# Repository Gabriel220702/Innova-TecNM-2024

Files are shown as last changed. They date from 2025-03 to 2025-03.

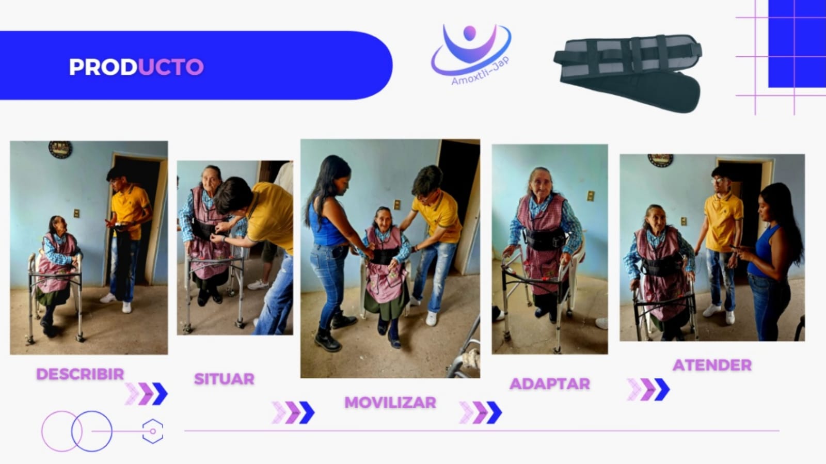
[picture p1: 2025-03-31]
Innova TecNM 2024 Etapa Regional/Página Web/img/portfolio/Producto.jpg

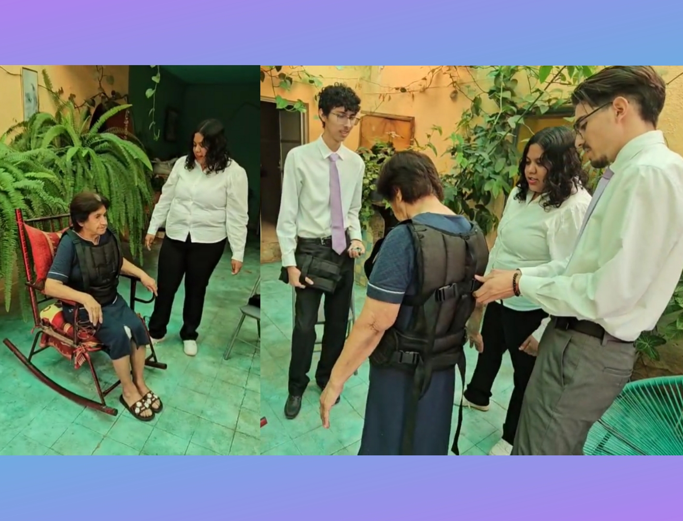
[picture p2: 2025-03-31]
Innova TecNM 2024 Etapa Regional/Página Web/img/portfolio/Abuelita con Chaleco 2.jpg

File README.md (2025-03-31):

# 💜**Amoxtli-Jap**💜  

## 📌 **Autor:** Gabriel Carrizales  
📍 **Institución:** Instituto Tecnológico Superior de la Región de los Llanos (ITSRLL)  
🎓 **Carrera:** Ingeniería Mecatrónica  

---

## 📖 **Descripción del Proyecto**  
Amoxtli-Jap es un dispositivo vestible en forma de cinturón o chaleco diseñado para mejorar la seguridad y bienestar de adultos mayores. Su innovador diseño integra sensores y tecnología para la detección de caídas y ubicación en tiempo real, ofreciendo una solución eficiente para el monitoreo y asistencia de personas vulnerables.  

---

## 📂 **Características Principales**  

🔹 **Diseño Ergonómico** 🎽  
- Fabricado con materiales textiles cómodos y resistentes.  

🔹 **Tecnología Integrada** 🔌  
- ESP32, GPS Neo-6M, giroscopio/acelerómetro MPU6050, buzzer, push button y baterías recargables.  

🔹 **Detección de Caídas** ⚠️  
- Sistema de monitoreo en tiempo real para alertar a familiares o cuidadores.  

🔹 **Ubicación en Tiempo Real** 🌍  
- Integración con Google Maps para rastrear la posición del usuario.  

🔹 **Alertas de Emergencia** 📢  
- Notificaciones inmediatas mediante sonido y mensajes vía WhatsApp.  

---

## 🏆 **Participación en Eventos**  
Amoxtli-Jap ha sido presentado en diversas competencias y ferias tecnológicas, destacando en las siguientes etapas:  

1. 🏫 **Innovatec Etapa Local** - Instituto Tecnológico Superior de la Región de los Llanos, Guadalupe Victoria, Durango.  
2. 🏙️ **Innovatec Etapa Regional** - Instituto Tecnológico de Nuevo León, Monterrey, Nuevo León.  
3. 🏅 **COCYTED** - Centro de Ciencia y Tecnología del Estado de Durango, Victoria de Durango, Durango.  

---

## 👥 **Integrantes del Equipo**  
El proyecto ha sido desarrollado por un equipo comprometido de estudiantes de Ingeniería Mecatrónica e Ingeniería en Administración de Empresas, enfocados en la innovación y aplicación de tecnología para el beneficio social.  

---

## 💻 **Tecnologías Utilizadas**  
✅ **ESP32** – Microcontrolador principal  
✅ **Neo-6M** – GPS para ubicación  
✅ **MPU6050** – Sensor de aceleración y giroscopio  
✅ **Python y C++** – Programación de algoritmos  
✅ **Google Maps API** – Integración de geolocalización  

---

## 📩 **Contacto**  
Para más información sobre el proyecto Amoxtli-Jap, puedes ponerte en contacto a través de [amoxtlijap2024@gmail.com] o visitar nuestra página oficial o redes sociales.  

📌 **Página Oficial:** [Amoxtli-Jap](https://home.amoxtli-jap.com/index.php)  
📌 **Facebook:** [Amoxtli-Jap en Facebook](https://www.facebook.com/profile.php?id=61563272744083)  
📌 **YouTube:** [Amoxtli-Jap en YouTube](https://www.youtube.com/@Amoxtli-Jap)  

---

<p align="center">

  
  
  

</p> 

🚀 **¡Innovando por el bienestar de nuestros adultos mayores!** 💙💜

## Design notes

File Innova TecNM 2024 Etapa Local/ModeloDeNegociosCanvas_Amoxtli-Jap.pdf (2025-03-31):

SOCIOS CLAVE | ACTIVIDADES CLAVE
PROPUESTA DE VALOR

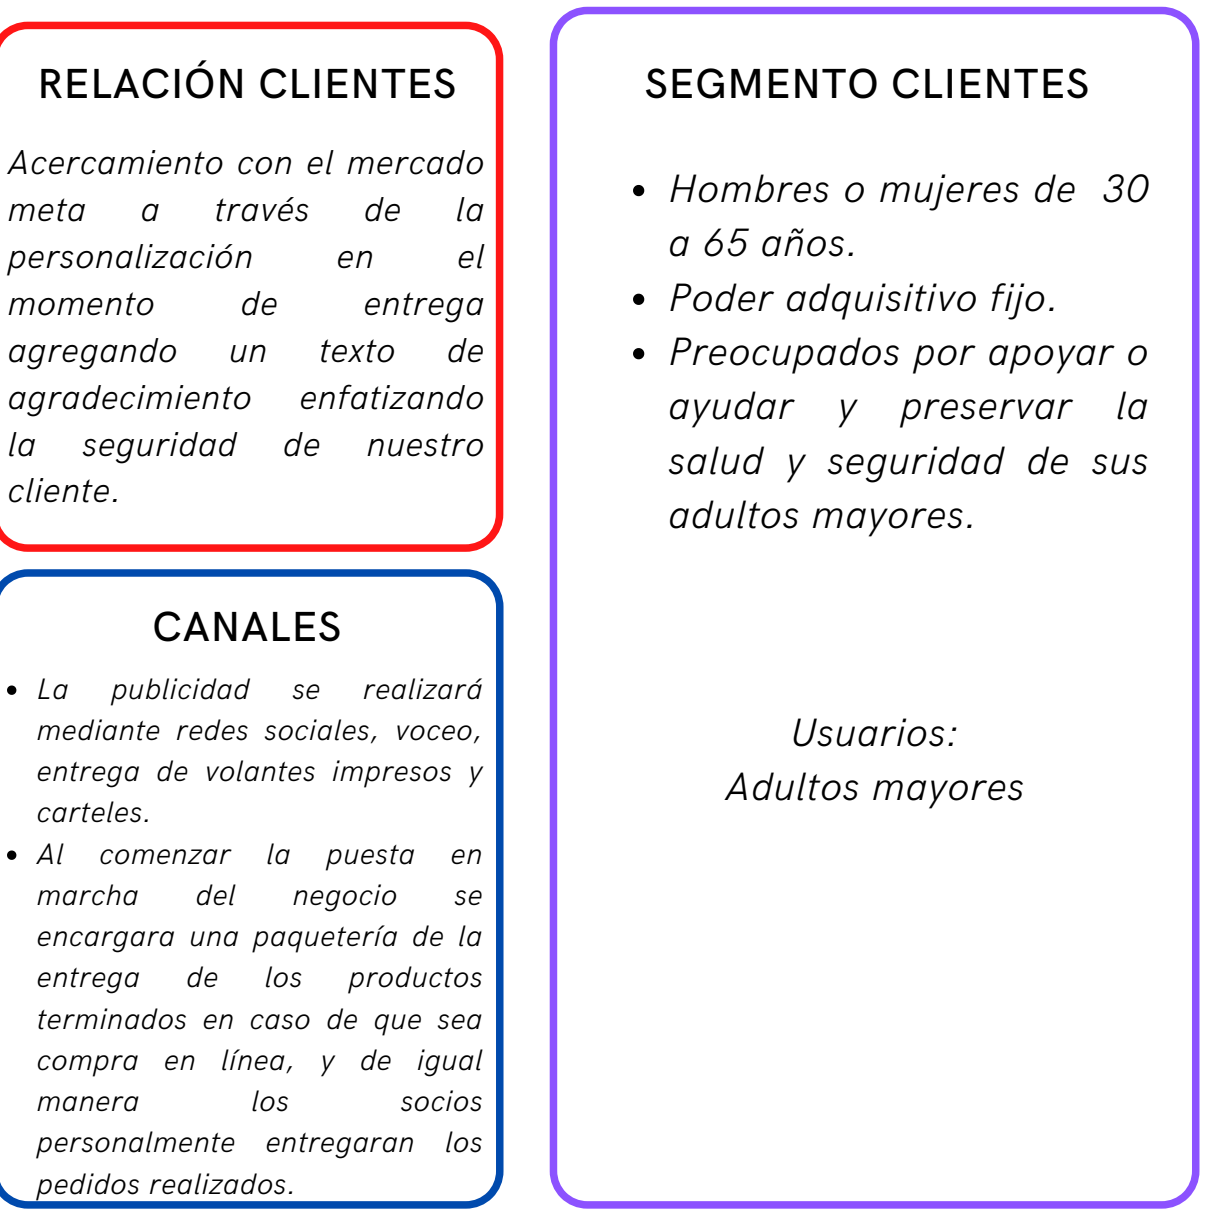
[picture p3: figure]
CANALES; RELACIÓN CLIENTES; SEGMENTO CLIENTES; Hombres o mujeres de 30 a 65 años. Poder adquisitivo fijo. Preocupados por apoyar o ayudar y preservar la salud y seguridad de sus adultos mayores.; Usuarios: Adultos mayores; publicidad; realizará; mediante redes sociales, voceo, entrega de volantes impresos y carteles. Al comenzar la puesta en; marcha; del; negocio; encargara una paquetería de la; entrega; los; productos; terminados en caso de que sea compra en línea, y de igual; manera; socios; personalmente entregaran los pedidos realizados.; Acercamiento con el mercado; meta; través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
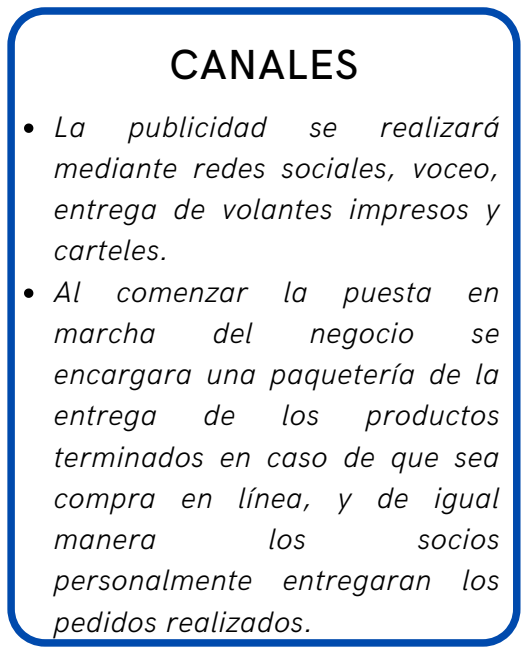
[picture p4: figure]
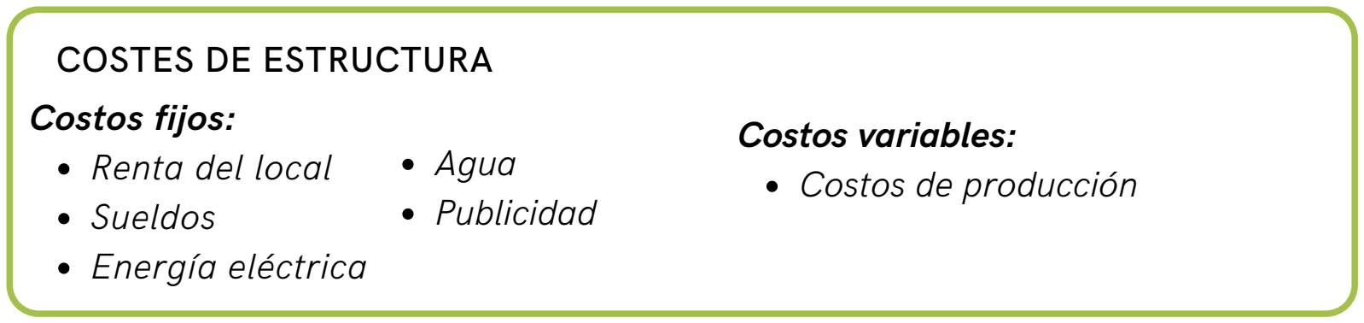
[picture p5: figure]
COSTES DE ESTRUCTURA Costos fijos: Renta del local Sueldos Energía eléctrica; Costos variables: Costos de producción; Agua Publicidad

FUENTES DE INGRESO

# M O DE L O DE N E G O CI O S CA N VAS A M O XT L I - JAP

Dispositivo auxiliar de monitoreo para facil movilidad y traslado de
adultos | mayores, | implentando
tecnología sensorial y ergonomía para el cuidado de adultos mayores. Mediante el monitoreo
constante | de | movimientos | y
respuesta rápida ante caídas. Ayudando a generar un resgitro de estadísticas vitales para medidas preventivas. Diseño ergonómico y
funcional | que | prioriza | la
comodidad | y | seguridad | del
usuario. | Genera | confianza | y
dignidad | en | situaciones | de
emergencia. Líder en innovación y
cuidado | personalizado | para
poblaciones vulnerables.

Adquisición de materia prima
(Sensores, | tarjeta | de
conectividad, telas, etc.)
Ensamble y programación de circuito y cinturón
Prueba de tarjeta de conectividad y de sensores
Actividades de mercadotecnia Distribuir el producto
Innovacion | y | desarrollo
tecnológico

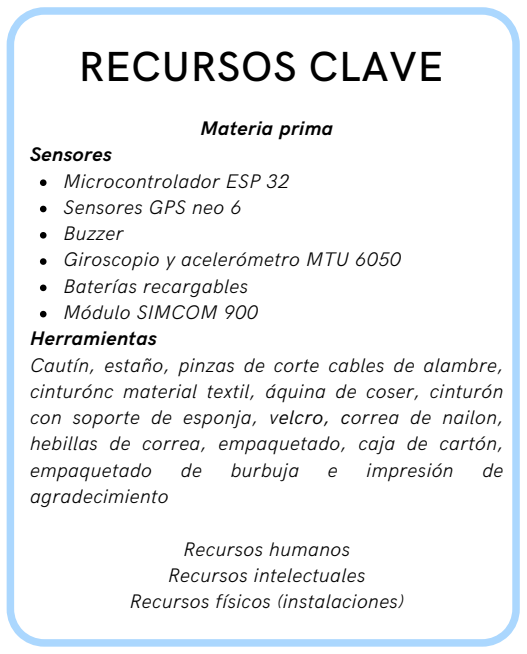
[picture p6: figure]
RECURSOS CLAVE; Materia prima; Sensores Microcontrolador ESP 32 Sensores GPS neo 6 Buzzer Giroscopio y acelerómetro MTU 6050 Baterías recargables Módulo SIMCOM 900 Herramientas; empaquetado; burbuja; impresión; agradecimiento; Recursos humanos Recursos intelectuales Recursos físicos (instalaciones)

Cautín, estaño, pinzas de corte cables de alambre, cinturónc material textil, áquina de coser, cinturón con soporte de esponja, velcro, correa de nailon, hebillas de correa, empaquetado, caja de cartón,

Comercios en línea o de la región que se dediquen a la electrónica.
Comercios que se dediquen a la venta de textiles.
Socios de plataformas en
venta | de | productos
ortopédicos.
Farmacias físicas

La principal fuente de ingresos será la venta de los cinturones con sensores en $1,200.00 MXN
Los pagos se recibirán en efectivo, de contado y en transferencias.

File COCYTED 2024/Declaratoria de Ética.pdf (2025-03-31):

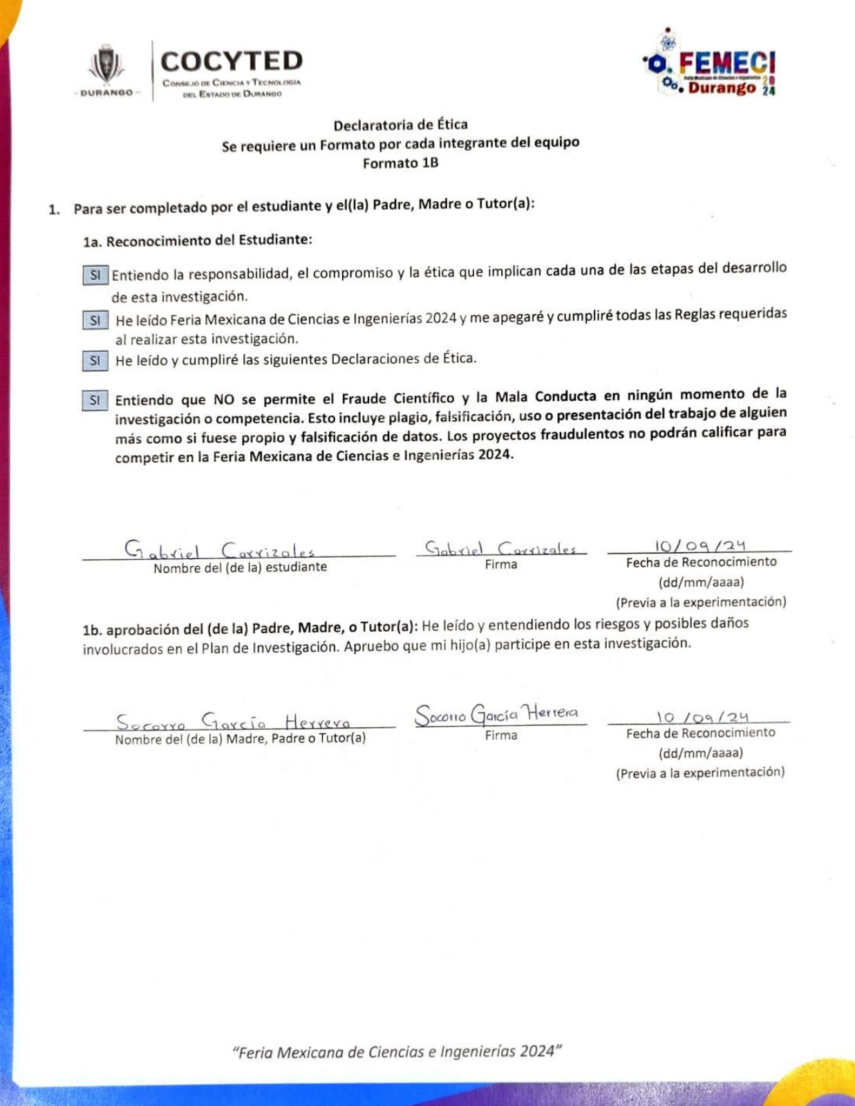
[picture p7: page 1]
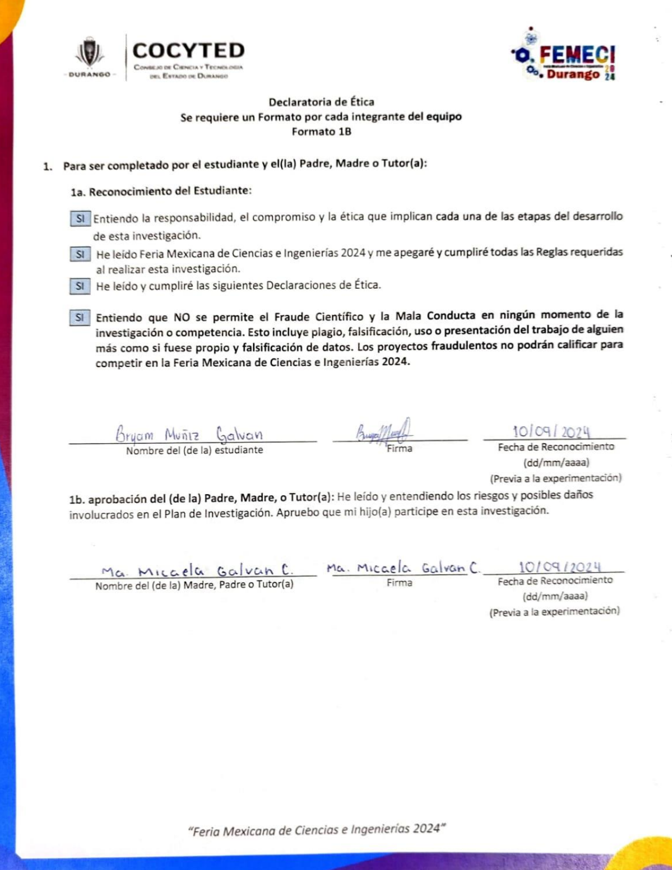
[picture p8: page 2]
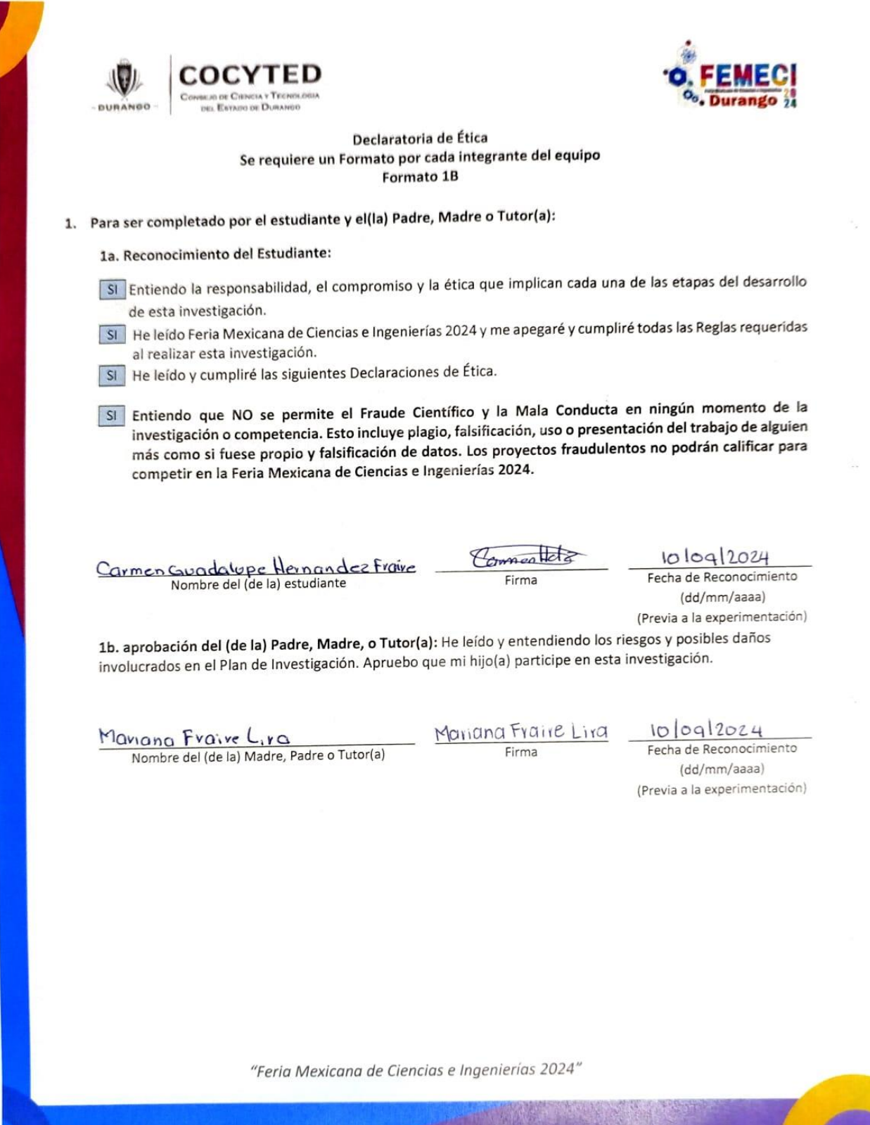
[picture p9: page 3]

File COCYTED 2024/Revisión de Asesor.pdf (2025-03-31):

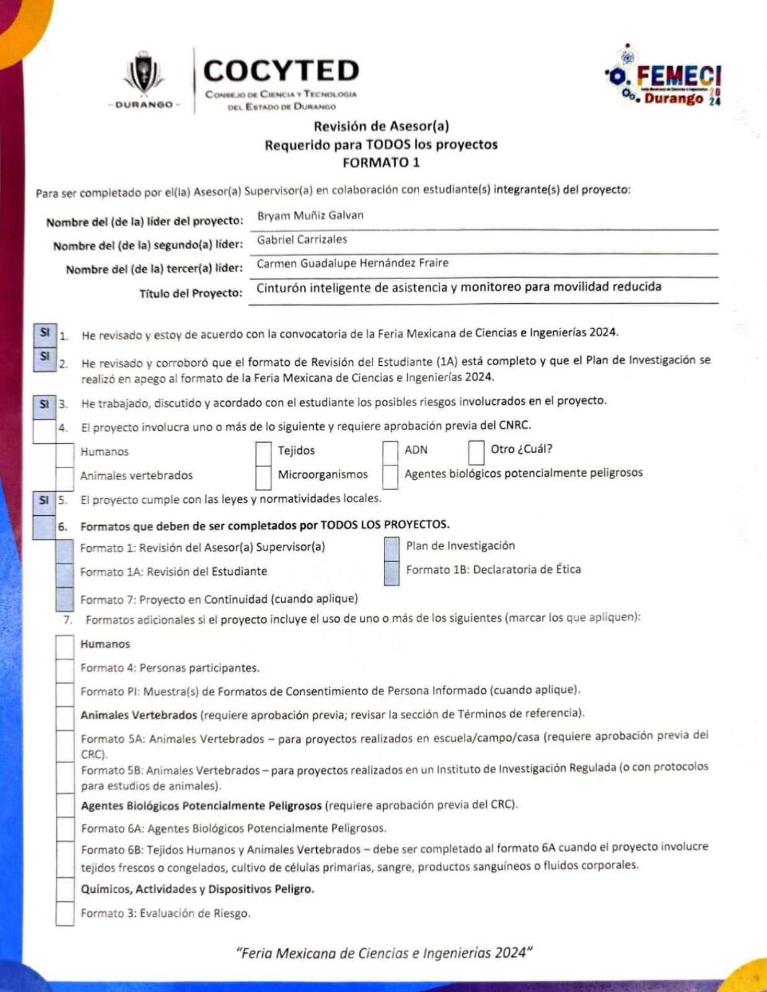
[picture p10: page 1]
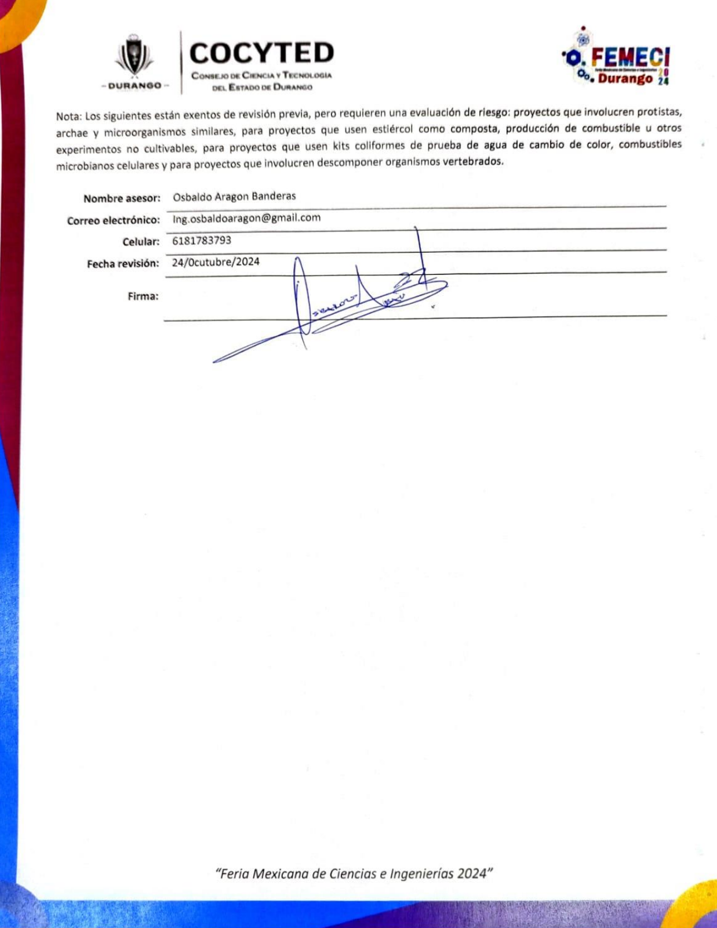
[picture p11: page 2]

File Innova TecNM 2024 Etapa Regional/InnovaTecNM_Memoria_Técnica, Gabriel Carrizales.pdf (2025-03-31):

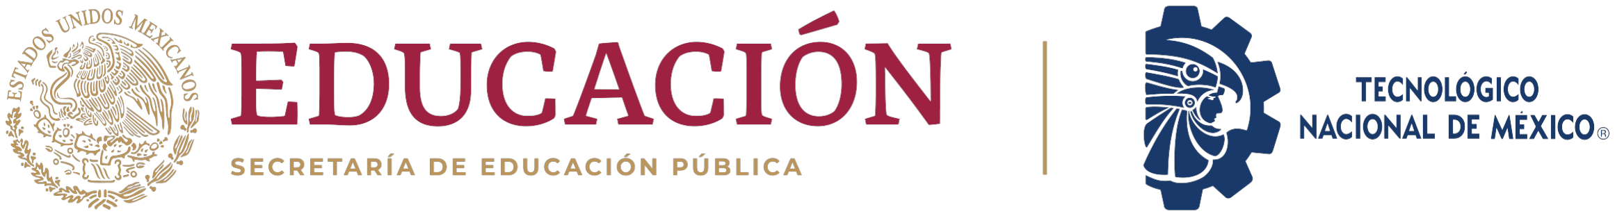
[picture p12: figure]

Cumbre Nacional de Desarrollo Tecnológico, Emprendimiento e Innovación, InnovaTecNM 2024 Instituto Tecnológico Superior de La Región de los Llanos
Región 2
Etapa Regional
MEMORIA DEL PROYECTO
Folio: | 54384-15 | Nombre corto: | Amoxtli-Jap
Nombre descriptivo: | Cinturón auxiliar para monitoreo de alerta para la detección de caídas en adultos mayores.
Categoría: | Servicios para la Salud
Área de aplicación: | Salud y bienestar de los adultos mayores
Naturaleza técnica: | Ciencias Eléctricas

Autores
BRYAM MUÑIZ GALVAN | Ing. en Mecatrónica | 6
GABRIEL CARRIZALES | Ing. en Mecatrónica | 6
ABRIL ADRIANA SANCHEZ VALENZUELA | Ing. en Administración | 6
CARMEN GUADALUPE HERNANDEZ FRAIRE | Ing. en Mecatrónica | 6
MIGUEL ÁNGEL RODRIGUEZ HERNANDEZ | Ing. en Mecatrónica | 6

Asesores
OSBALDO ARAGÓN BANDERAS | ing.osbaldoaragon@gmail.com
JESUS LEONEL ARCE VALDEZ | jlaitsrll@hotmail.com

ER. SS. Descripción de la propuesta

El objetivo del dispositivo se centra en proporcionar traslados seguros para los usuarios y optimizar la capacidad de respuesta ante eventos críticos, minimizando el riesgo de lesiones graves derivadas de caídas. Además, brinda una mayor sensación de seguridad a los usuarios y sus familias, gracias a la implementación de sujetadores de alta resistencia que facilitan traslados por parte de cuidadores para quienes lo necesitan.

Amoxtli-Jap es un avanzado dispositivo de monitoreo médico vestible, diseñado para el seguimiento de adultos mayores y personas con movilidad reducida. El dispositivo está integrado con sensores de alta precisión que permiten un monitoreo continuo y detallado del posicionamiento y movilidad del usuario. Su operatividad se fundamenta en la implementación de tecnología de vanguardia, incluyendo sensores de caídas y algoritmos de procesamiento de datos, que permiten analizar los patrones de movimiento en tiempo real.

Al detectar una anomalía en el movimiento, como una caída, Amoxtli-Jap activa automáticamente un protocolo de alerta. El cual comunica el incidente de forma inalámbrica a familiares, cuidadores o sistemas de respuesta médica de emergencia, garantizando una intervención rápida.

Amoxtli-Jap sobresale en el ámbito biomédico al integrar estas tecnologías enfocadas en promover el bienestar de los usuarios. Además, implementa una página web vinculada a una aplicación móvil que notifica de inmediato ante la detección de una caída, permitiendo una acción rápida. Este enfoque no solo mejora significativamente la seguridad y calidad de vida de los individuos vulnerables, sino que también contribuye a una gestión proactiva de la salud en el hogar.

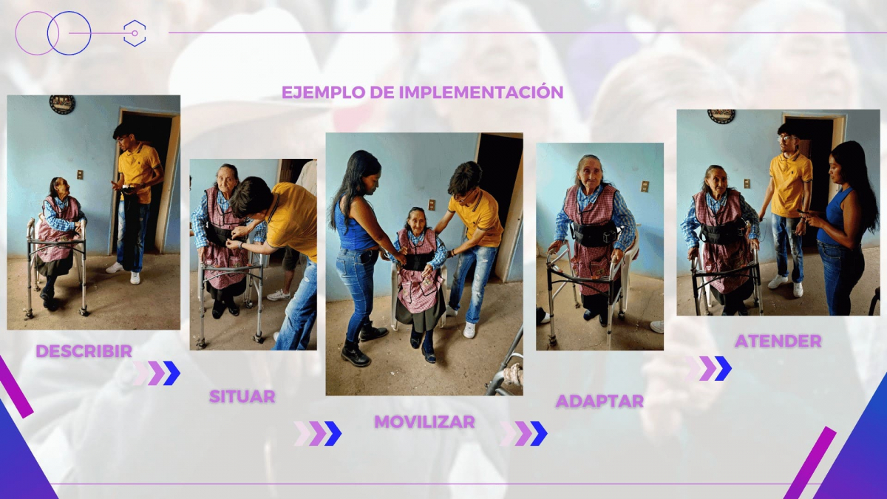
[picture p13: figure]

ER. SS. Descripción de la problemática y justificación

Las caídas representan una de las principales causas de lesiones graves, discapacidades e incluso muerte en adultos mayores. Según la CENAPRACE en 2017, y en base a estudios de la OMS, las caídas son eventos repentinos e involuntarios que afectan especialmente a los adultos mayores, con tasas de prevalencia que van desde el 15% al 28%, aumentando al 35% a partir de los 75 años. En México, la situación es alarmante, con una tasa de prevalencia del 26.5%, indicando una tendencia creciente con la edad. Estas caídas conllevan diversas complicaciones para la salud, incluyendo fracturas, inmovilidad, estrés postraumático y deterioro neurocognitivo, lo cual afecta negativamente la calidad de vida en este grupo. (CENAPRACE, 2017)

Amoxtli-Jap se presenta como una solución innovadora y proactiva. Diseñado con un enfoque en inclusión y equidad, el dispositivo garantiza que las personas mayores o con movilidad reducida, reciban una asistencia de manera cómoda y segura, además de una detección temprana y una respuesta efectiva ante caídas. Utilizando tecnología avanzada, Amoxtli-Jap monitorea continuamente los movimientos del usuario para detectar una caída. Esto permite una alerta automática a cuidadores o familiares, asegurando una asistencia rápida y eficiente. Mejorando la calidad de vida, y manteniendo una independencia mientras se reduce la carga emocional y económica.

Amoxtli-Jap facilita la prevención de lesiones graves y hospitalizaciones prolongadas, el dispositivo contribuye a la sostenibilidad económica del sistema de salud, reduciendo los costos asociados con las caídas y optimizando el uso de recursos médicos. Además, al incorporar tecnologías disruptivas de la Industria 4.0, como el análisis de datos y la comunicación inalámbrica, mejorando la precisión y efectividad del monitoreo de caídas, representando un avance significativo en el cuidado de la salud.

Amoxtli-Jap se alinea con las megatendencias globales hacia el envejecimiento de la población, la creciente demanda de soluciones tecnológicas en salud y el impulso hacia la atención personalizada y preventiva. La propuesta no solo aborda una problemática crítica en salud pública, sino que también introduce una solución innovadora que puede transformar positivamente la atención y calidad de vida de los adultos mayores a nivel local, regional y más allá.

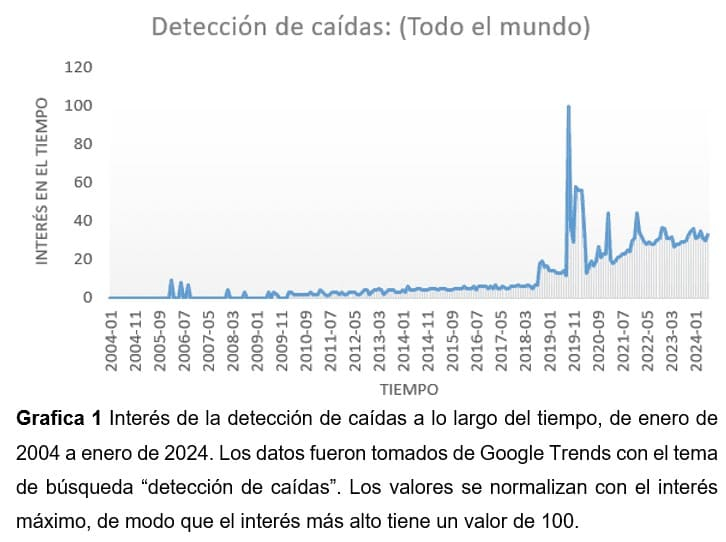
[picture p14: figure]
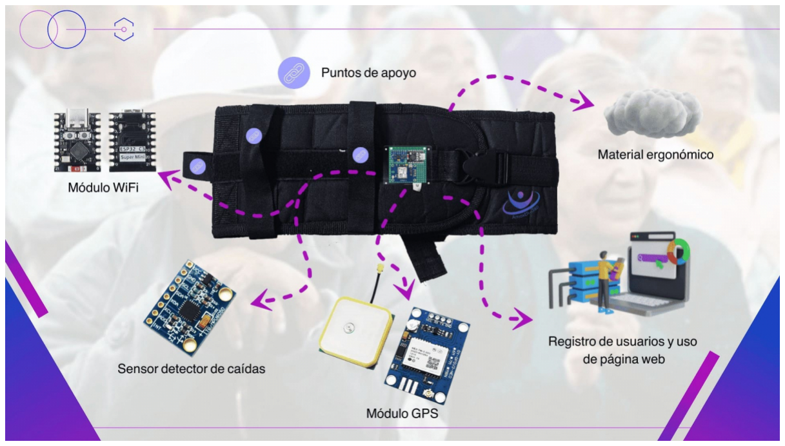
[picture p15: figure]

ER. SS. Estado del arte y/o de la técnica

Existen diversos estudios de revisión que abordan el desarrollo de la detección de caídas desde múltiples perspectivas. Debido al rápido avance de los sensores inteligentes y los enfoques analíticos relacionados, es fundamental actualizar periódicamente las tendencias y avances en este campo. Elegimos los artículos de revisión más relevantes, publicados entre 2019 y 2023 en Google Scholar y Scielo, que ofrecen soluciones a la problemática en común.

En el mercado actual, existen diversos dispositivos de alerta médica y sistemas de detección de caídas portables e inteligentes. Con el objetivo de mejorar la seguridad de los usuarios mediante la detección y alerta temprana de caídas, mismas que pueden representar un alto riesgo y a su vez generar preocupación en familiares y cuidadores al desconocer si se encuentran seguros o han sufrido algún accidente mientras realizan sus actividades diarias.

En la Revista Chilena de Ingeniería se publicó un sistema con tecnología Kinect 2.0 que monitorea pacientes y envía alertas al correo del cuidador en caso de caídas. Utiliza iPi Mocap Studio y LabVIEW para analizar biomecánicamente las caídas y detectar cambios en la posición y velocidad del paciente. (Quinayás et al, 2020)

Por otro lado, se desarrolló un sistema inteligente de alerta ante caídas de adultos mayores. El sistema reconoce y alerta sobre caídas a través de un brazalete que porta el usuario, dicha detección se da mediante la recolección de datos en tiempo real y la combinación de redes neuronales LSTM. (Guerrero, 2023)

En el desarrollo de tesis de titulación se planteó un sistema de asistencia centrado en un botón de ayuda portable aplicando un SOC GSM+GPS el cual es similar a la propuesta planteada por la empresa encarda de desarrollar SkyAngel 4G. (Romero & Moises, 2019)

Como se mencionó en el punto anterior, una opción en el mercado para la detección de caídas de adultos mayores que cuenta con un sistema de alerta médica es el dispositivo “Colgante de alerta SOS - SkyAngel 4G” con un precio estimado de US $179.79 en plataformas oficiales de ventas en línea como lo es Amazon.

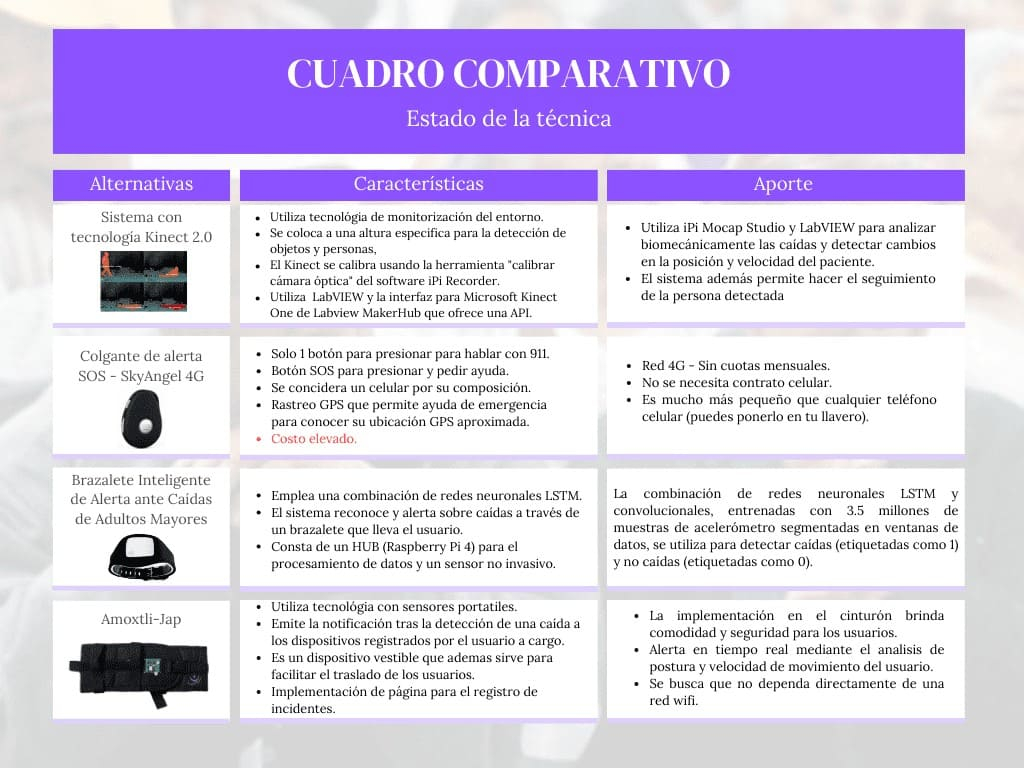
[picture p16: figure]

ER. SS. Impacto de la Innovación y propuesta de valor en el sector estratégico

Amoxtli-Jap es un dispositivo innovador que combina tecnología avanzada y diseño ergonómico para mejorar la seguridad y asistencia de los adultos mayores y personas con movilidad reducida. Utiliza el ESP32 para conectividad WiFi, un módulo GPS, y sensores para detectar caídas. Su diseño incluye soportes que facilitan la maniobrabilidad, ayudando tanto a la persona que ha sufrido la caída como a quien le asiste, optimizando así la respuesta en

emergencias.

Este dispositivo monitorea los movimientos del usuario por medio de una página web y que, a su vez, está enlazada a una app móvil, identificando patrones que indican caídas y enviando alertas y ubicación automáticas a familiares o cuidadores para asegurar una intervención rápida. Su diseño ergonómico facilita la asistencia, mientras que la recopilación de datos permite un mejor análisis de riesgos y medidas preventivas. Esto aumenta la independencia y seguridad de los usuarios, aliviando la carga emocional sobre sus familias.

El dispositivo se destaca por su diseño práctico y la integración de tecnología accesible, en contraste con dispositivos más complejos. Su enfoque preventivo y la capacidad de recopilar datos de caídas lo diferencian de otros productos en el mercado. Además, mejora la maniobrabilidad y asistencia durante traslados, una característica única en comparación con otros dispositivos existentes.

Amoxtli-Jap reduce el tiempo de respuesta en emergencias y mejora las tasas de recuperación. Su capacidad de recopilar y analizar datos estadísticos sobre caídas permite implementar medidas preventivas, mejorando así la gestión de la salud y el bienestar de los usuarios.

Amoxtli-Jap tiene el potencial de establecer nuevos estándares en el cuidado de los adultos mayores mediante la incorporación de tecnologías emergentes y un diseño centrado en la facilidad de uso y la eficacia. Esta innovación no solo reduce los costos asociados con las caídas, sino que también promueve la inclusión y mejora la calidad de vida de este grupo vulnerable, facilitando el acceso a tecnologías de asistencia para adultos mayores de diferentes capacidades físicas y tecnológicas.

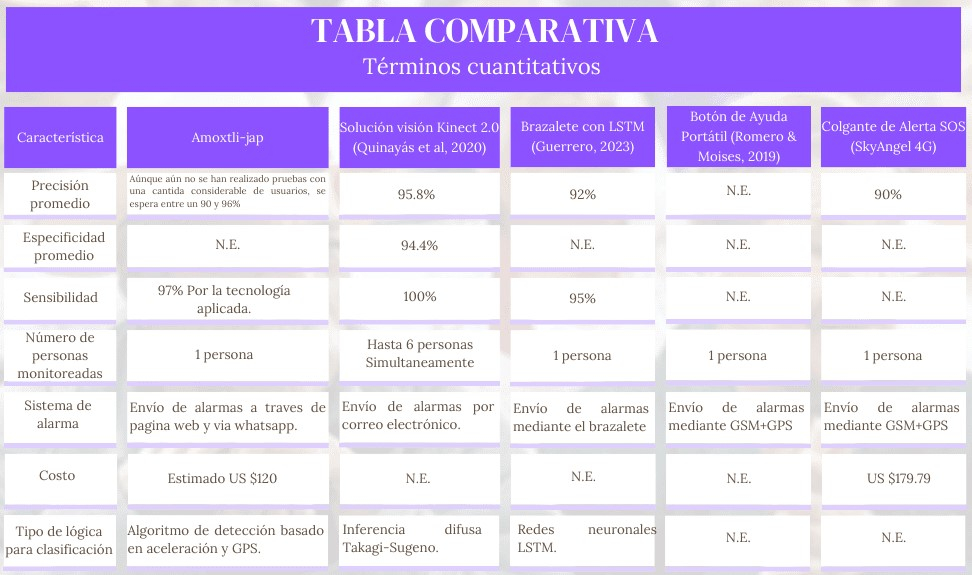
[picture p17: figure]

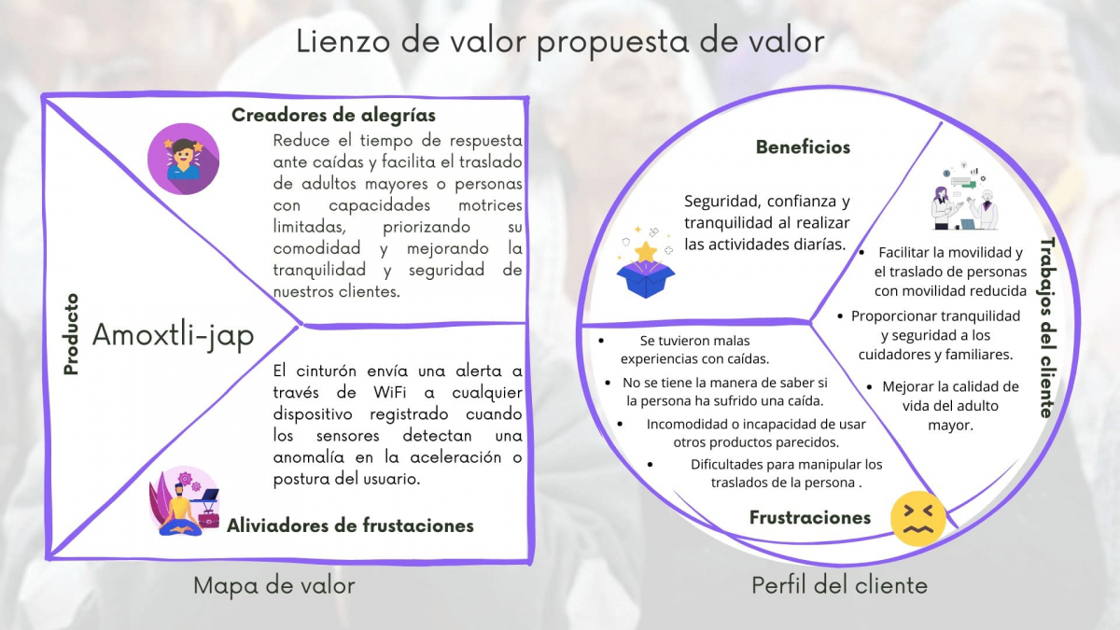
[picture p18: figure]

ER. SS. Factibilidad tecnológica y normatividad aplicable

Acceso a la Tecnología Clave

Para la producción y desarrollo de Amoxtli-Jap, se requiere acceso a diversas tecnologías y equipos clave, en primera instancia, componentes electrónicos para conectividad Wifi, GPS para geolocalización, y sensor acelerómetro y giroscopio para la detección de caídas. Por otra parte, herramientas para el desarrollo del software, tales como (Arduino IDE, Visual Studio Code, Ionic framework, Android studio y Google firebase). Este último, sirviendo como sistema para almacenar y gestionar los datos recopilados, asegurando su disponibilidad para el análisis y medidas preventivas.

Uso de Tecnologías Disruptivas 4.0

Amoxtli-Jap emplea varias tecnologías disruptivas 4.0 a lo largo de su desarrollo y comercialización, ya que el IoT permite la interconexión de dispositivos y recopilación de datos en tiempo real, la Big Data analiza datos para identificar patrones de caídas y riesgos asociados, y finalmente la comunicación inalámbrica permite la utilización de Wifi para asegurar la conectividad constante y la transmisión de datos en tiempo real.

Nivel de Madurez de la Tecnología (TRL)

De acuerdo con la matriz del Nivel de Madurez de la Tecnología (TRL), Amoxtli-Jap se encuentra en el TRL 4, ya que el dispositivo ha sido probado en entornos simulados y adentrándose a entornos reales, y ha mostrado resultados positivos en cuanto a la detección de caídas y la transmisión de alertas.

Normatividad de la Legislación Nacional e Internacional

En Amoxtli-Jap nos aseguraremos de que cada dispositivo fabricado cumpla con la NOM-241-SSA1-2012, reflejando nuestro compromiso con los más altos estándares de calidad y seguridad exigidos por la Secretaría de Salud y COFEPRIS. Esta dedicación a la calidad, se extiende al cumplimiento de las normativas de seguridad para dispositivos electrónicos dictadas por la Secretaría de Energía y la Secretaría de Economía. Nuestros procesos estarán en línea con las NOM-001-SCFI-2018 y NOM-024-SCFI-2013, así como con las directrices de manejo de residuos electrónicos de la SEMARNAT, incluyendo las NOM-161-SEMARNAT-2011 y NOM-052-SEMARNAT-2005. A nivel internacional, adoptaremos las normas ISO 9001 para nuestros sistemas de gestión, y para dispositivos IoT que procesan datos sensibles, nos adheriremos a la ISO/IEC 27001. Asegurando así que Amoxtli-Jap sea sinónimo de innovación responsable y segura.

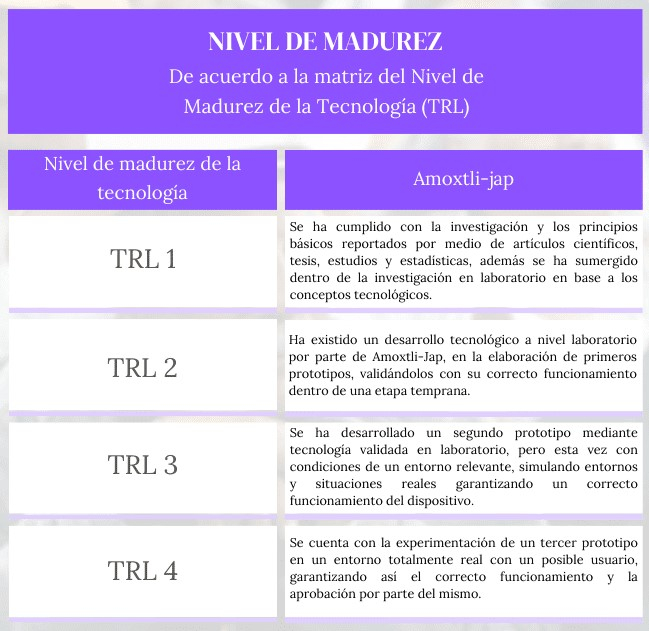
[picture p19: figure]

ER. SS. Propiedad Intelectual

Amoxtli-jap, considerando las figuras jurídicas que protegen el IMPI, el modelo de utilidad sería aplicable, dado que combina tecnologías existentes de forma novedosa y única, lo que nos permite proteger nuestra innovación. Además, es relevante en términos de derechos de autor, ya que buscamos proteger la base de datos obtenidos del sistema, así como el software asociado.

Para proteger esta innovación, debemos obtener una cuenta “pase” en el Instituto Mexicano de la Propiedad Industrial y proceder a realizar el pago y envío de documentos necesarias para obtener el modelo de utilidad.

Por la presentación de una solicitud de registro de un modelo de utilidad y sus anexos de hasta 30 hojas, así como por los servicios a que se refiere el artículo 38 de la ley $2,000.00 mxn + IVA, Por el concepto de cada hoja $61.00 mxn + IVA (se puede acceder a un 50% de descuento en ciertos casos)

Es posible proteger nuestro software y nuestra base de datos a través del modelo de obra literaria ofrecido por el Instituto Nacional del Derecho de Autor. El registro tiene un costo de $338.00 MXN.

ER. SS. Fuentes consultadas

CENAPRACE. | (2017). | CAIDAS. | Obtenido | de | Secretaría | de | Salud:
https://www.gob.mx/cms/uploads/attachment/file/482206/CAIDAS.pdf

DE JESUS, R. & MOISES, A. (2019). SISTEMA DE ASISTENCIA CENTRADO EN UN BOTÓN DE AYUDA PORTABLE APLICANDO UN SOC GSM+ GPS.

Amazon. (s.f.). Colgante de alerta SOS - SkyAngel 4G [Detector de caídas en adultos mayores]. Amazon. https://www.amazon.com/-/es/Assistive-Technology-Services-SkyAngel911FD-impermeable/dp/B075NT1ZGW

Guerrero, L. D. (2023) Sistema Inteligente de Alerta ante Caídas de Adultos Mayores

Quinayás, C. A., Quintero, D. F., Ruíz, E., & Narváez, J. L. (2020). Sistema de detección de caídas en personas utilizando vídeo vigilancia [Fall detection system for people using video surveillance]. Ingeniare. Revista chilena de ingeniería, 28(4), 684-693. https://doi.org/10.4067/S0718-33052020000400684

Powered by TCPDF (www.tcpdf.org)

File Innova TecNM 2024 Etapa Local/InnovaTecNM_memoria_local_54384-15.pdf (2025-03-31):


Cumbre Nacional de Desarrollo Tecnológico, Emprendimiento e Innovación, InnovaTecNM 2024 Instituto Tecnológico Superior de La Región de los Llanos
Etapa Local. Región 2
MEMORIA DEL PROYECTO
Folio: | 54384-15 | Nombre corto: | Amoxtli-Jap
Nombre descriptivo: | Cinturón auxiliar para monitoreo de alerta para la detección de caídas en adultos mayores.
Categoría: | Servicios para la Salud
Área de aplicación: | Salud y bienestar de los adultos mayores
Naturaleza técnica: | Ciencias Eléctricas

Autores
BRYAM MUÑIZ GALVAN | Ing. en Mecatrónica | 6
GABRIEL CARRIZALES | Ing. en Mecatrónica | 6
ABRIL ADRIANA SANCHEZ VALENZUELA | Ing. en Administración | 6
CARMEN GUADALUPE HERNANDEZ FRAIRE | Ing. en Mecatrónica | 6
MIGUEL ÁNGEL RODRIGUEZ HERNANDEZ | Ing. en Mecatrónica | 6

Asesores
OSBALDO ARAGÓN BANDERAS | ing.osbaldoaragon@gmail.com
JESUS LEONEL ARCE VALDEZ | jlaitsrll@hotmail.com

SS. Descripción de la propuesta Amoxtli-Jap es un avanzado dispositivo de monitoreo médico en forma de cinturón, diseñado específicamente para el seguimiento de adultos mayores. Este dispositivo está integrado con sensores de alta precisión que permiten una vigilancia continua y detallada del posicionamiento y movilidad del usuario. Su funcionamiento se basa en la utilización de tecnología de vanguardia, que incluye sensores giroscópicos y acelerómetros, junto con algoritmos sofisticados de procesamiento de datos para analizar los patrones de movimiento en tiempo real.

Al identificar una anomalía en el movimiento, como podría ser una caída, Amoxtli-Jap activa automáticamente un protocolo de alerta. Este protocolo comunica el incidente de forma inalámbrica a familiares, cuidadores o sistemas de respuesta médica de emergencia, asegurando una intervención rápida y eficaz.

El objetivo principal de este sistema es optimizar la capacidad de respuesta ante eventos críticos, minimizando así el riesgo de lesiones graves que pueden resultar de caídas. Además, proporciona una mayor sensación de seguridad a los usuarios y sus familias, permitiendo que los adultos mayores mantengan una vida más independiente y segura en su entorno habitual.

Este enfoque no solo mejora significativamente la seguridad y la calidad de vida de los individuos vulnerables, sino que también contribuye a la gestión proactiva de la salud en el ámbito domiciliario, reduciendo potencialmente la carga y los costos asociados a la atención médica de urgencias y hospitalizaciones prolongadas.

SS. Descripción de la problemática Las caídas en adultos mayores constituyen una de las principales causas de lesiones graves, discapacidades, e incluso la muerte. A menudo, estas son trivializadas como eventos normales, reflejando en pacientes, personal de salud y familiares, poca conciencia sobre su seriedad.

Según la OMS, una caída es evento que precipita al individuo al suelo, siendo un fenómeno repentino e involuntario. Estudios epidemiológicos revelan que estas son especialmente frecuentes en adultos mayores, con tasas de entre 15%

y 28%, incrementándose al 35% a partir de los 75 años.

En México, la prevalencia de caídas en personas mayores es alarmante, con una tasa del 26.5%, y con una tendencia a incrementarse con la edad. Estas caídas frecuentemente se asocian con complicaciones de salud como fracturas, inmovilidad, estrés postraumático y deterioro neurocognoscitivo, aumentando el riesgo de caídas.

Ante esta problemática, Amoxtli-Jap se presenta como una solución proactiva. Diseñado bajo los principios de inclusión y equidad, asegura que adultos mayores, independientemente de su habilidad física o nivel tecnológico, reciban una detección y respuesta temprana ante caídas. El dispositivo utiliza el análisis de datos para monitorear los movimientos del usuario, detectando patrones que indican una caída y alertando automáticamente a personas de confianza para asegurar una asistencia rápida y eficaz.

Este enfoque no solo tiene el potencial de salvar vidas y fomentar una recuperación más eficaz, sino que también mejora la calidad de vida de este sector, permitiéndoles mantener su independencia mientras reduce la carga emocional y económica sobre ellos y sus familias. Además, al incorporar tecnologías disruptivas de la Industria 4.0, como el análisis de datos, Amoxtli-Jap refleja un impacto social significativo fortaleciendo la calidad de vida y la sostenibilidad económica de las comunidades a través de la reducción de los costos médicos asociados con las caídas.

SS. Estado de la técnica (estado del arte) En el mercado actual, existen diversos dispositivos de alerta médica y sistemas de detección de caídas con dispositivo portables e inteligentes. Con el objetivo de aumentar la seguridad de los adultos mayores mediante la alerta y detección temprana de caídas que pueden ser de alto riesgo y que en algunas ocasiones dificulta la tranquilidad de familiares y cuidadores al no conocer con exactitud si los adultos mayores se encuentran seguros o no han sufrido algún accidente al llevar a cabo sus actividades diarias, sobre al saber que pasen mayor parte de su tiempo solos.

Alternativas similares a la propuesta:

Como trabajo de titulación se diseñó y desarrollo un sistema inteligente basado en visión artificial y aplicaciones móviles para el monitoreo y detección de caídas en adultos mayores, Cuenca Ecuador en 2021. (Calva Bravo & Rodas Pérez, 2021)

Trabajo de Titulación previo a la obtención del título de Ingeniera en Electrónica e Instrumentación en donde desarrollaron un Sistema Inteligente de Alerta ante Caídas de Adultos Mayores esto mediante la implementación de un reloj inteligente y redes neuronales. (Guerrero, 2023)

Desarrollo de tesis de titulación de SISTEMA DE ASISTENCIA CENTRADO EN UN BOTÓN DE AYUDA PORTABLE APLICANDO UN SOC GSM+GPS. (Romero & Moises, 2019)

Por último, una opción en el mercado para la detección de caídas de adultos mayores que cuenta con un sistema de alerta médica es el dispositivo “Colgante de alerta SOS - SkyAngel 4G”

Se anexa imagen de tabla comparativa.

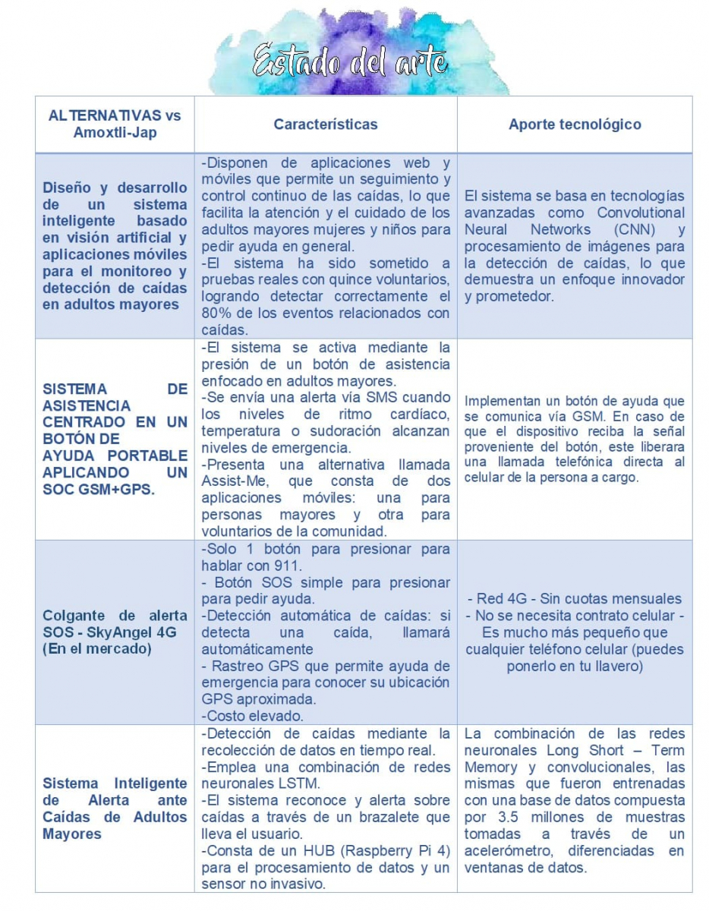
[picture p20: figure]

SS. Descripción de la innovación e impacto en el sector estratégico Amoxtli-Jap, integra tecnologías avanzadas como el ESP32 para conectividad WiFi y Bluetooth, un módulo GPS, y sensores de acelerómetro y giroscopio. Aunque el diseño se centra en una solución más sencilla en comparación con proyectos existentes, como los dispositivos basados en redes neuronales o dispositivos vestibles para detección de caídas, la innovación se encuentra en la eficacia y practicidad de su implementación tanto en diseño como en uso.

Amoxtli-Jap prioriza la detección temprana de caídas, utilizando datos del acelerómetro y el giroscopio para identificar patrones de movimiento anormales que puedan indicar una caída. Además, el diseño del cinturón tipo faja incluye soportes que facilitan la maniobrabilidad, ayudando tanto a la persona que ha sufrido la caída como a la que asiste en su levantamiento.
Este enfoque integral no solo mejora la seguridad de los adultos mayores sino que también optimiza la asistencia en situaciones de emergencia. Además, nuestro sistema recopila datos estadísticos sobre las caídas, incluyendo el número de incidentes y los lugares donde ocurren, lo que permite una mejor comprensión y análisis de los riesgos asociados.
Al incorporar tecnologías emergentes y un diseño centrado en la facilidad de uso y la eficacia, Amoxtli-Jap tiene el potencial de establecer nuevos estándares en el cuidado de los adultos mayores. Esta innovación puede generar un impacto económico y social significativo, reduciendo los costos asociados con las caídas y promoviendo un enfoque preventivo en el cuidado de la salud de nuestra población envejecida.

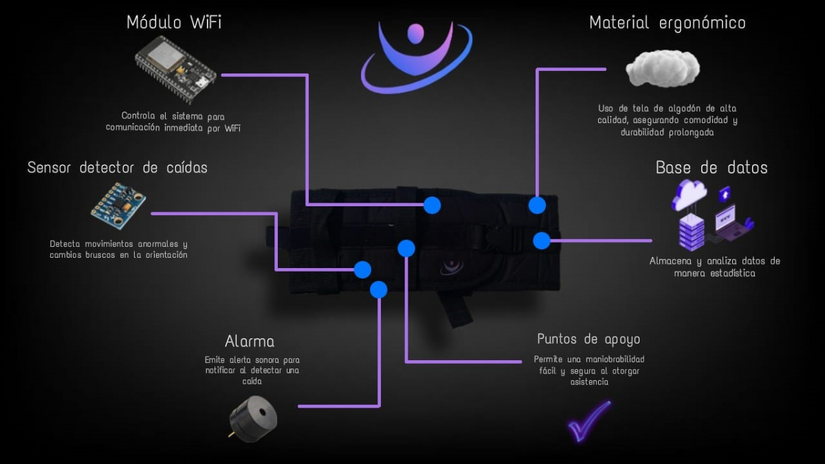
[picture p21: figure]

SS. Propuesta de valor
Amoxtli-Jap se distingue en el mercado por su integración única de tecnología sensorial y funcionalidades ergonómicas diseñadas específicamente para adultos mayores o individuos con limitaciones motrices. A diferencia de los sistemas convencionales que requieren de interacción manual para funcionar, nuestro cinturón equipado con modulo WiFi, módulo GPS y sensor detector de caídas, aprovecha la comunicación inalámbrica a distancia para monitorizar constantemente los movimientos del usuario, identificando patrones que indiquen una caída.
Esta característica permite una respuesta rápida y efectiva, crucial en emergencias médicas, donde el tiempo es un factor crítico. Además, Amoxtli-Jap registra estadísticas vitales sobre la frecuencia y ubicación de las caídas, proporcionando datos valiosos para futuras medidas preventivas y análisis médicos.
La innovación de Amoxtli-Jap también radica en su diseño; un cinturón tipo faja que no solo detecta caídas para facilitar la asistencia, sino que también gracias a puntos de apoyo integrados, se mejora la maniobrabilidad por parte de quien lo asiste durante traslados, priorizando la comodidad y seguridad del usuario.
Este enfoque suministra un grado elevado de confianza tanto a cuidadores y familiares como al propio usuario en general, ofreciendo un método más digno y práctico para manejar tales situaciones. Este diseño ergonómico y la tecnología sensorial de Amoxtli-Jap lo posiciona como líder en innovación y cuidado personalizado para la población vulnerable.

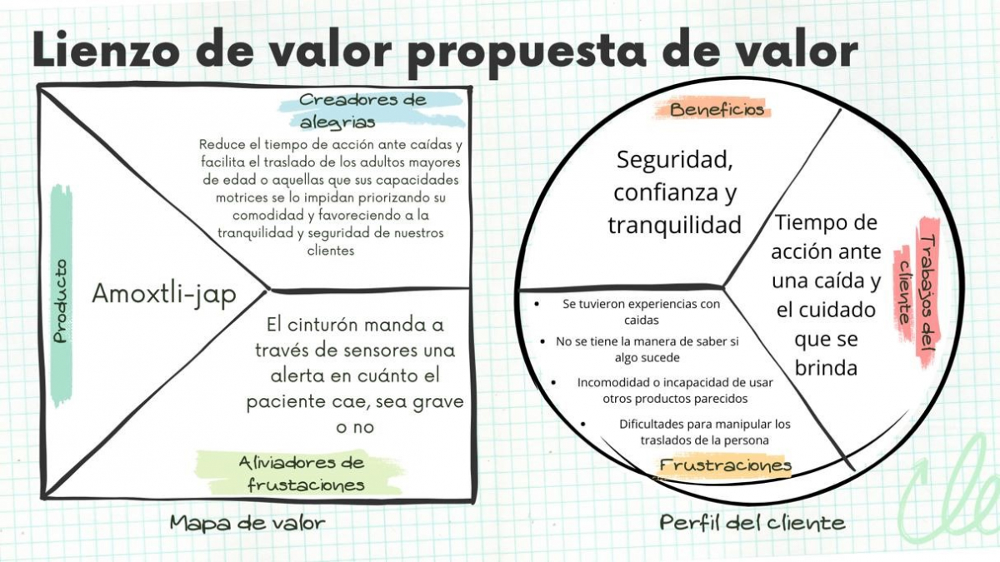
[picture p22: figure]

SS. Fuentes consultadas
Calva Bravo, B. X., & Rodas Pérez, W. H. (2021). Diseño y desarrollo de un sistema inteligente basado en visión artificial y aplicaciones móviles para el monitoreo y detección de caídas en adultos mayores (Bachelor's thesis).

Centro Nacional de Programas Preventivos y Control de Enfermedades. (2017). Guía de Consulta para el Médico de
Primer | Nivel | de | Atención. | Adherencia | Terapéutica | en | la | Persona | Adulta | Mayor.
https://www.gob.mx/cms/uploads/attachment/file/482206/CAIDAS.pdf

DE JESUS, ROMERO. & MOISES, A. (2019). SISTEMA DE ASISTENCIA CENTRADO EN UN BOTÓN DE AYUDA PORTABLE APLICANDO UN SOC GSM+ GPS.

eBay. (s.f.). Colgante de alerta SOS - SkyAngel 4G [Detector de caídas en adultos mayores]. eBay. https://www.ebay.com/itm/144761444033?

Guerrero Navarro, L. D. (2023) Sistema Inteligente de Alerta ante Caídas de Adultos Mayores

Powered by TCPDF (www.tcpdf.org)

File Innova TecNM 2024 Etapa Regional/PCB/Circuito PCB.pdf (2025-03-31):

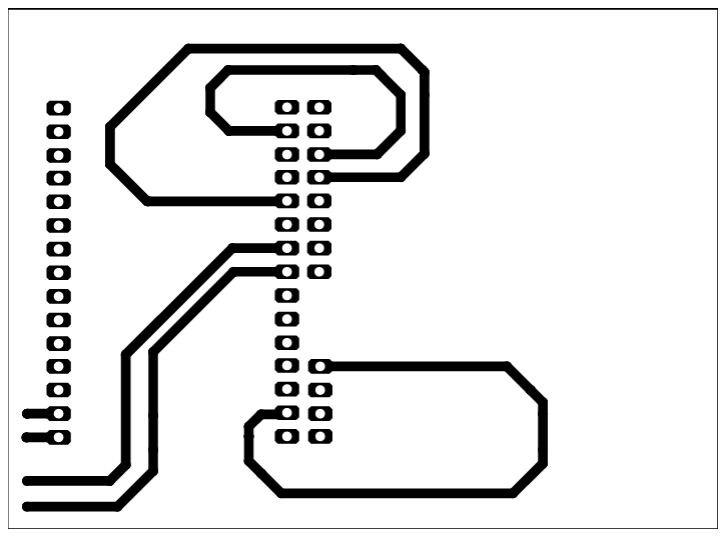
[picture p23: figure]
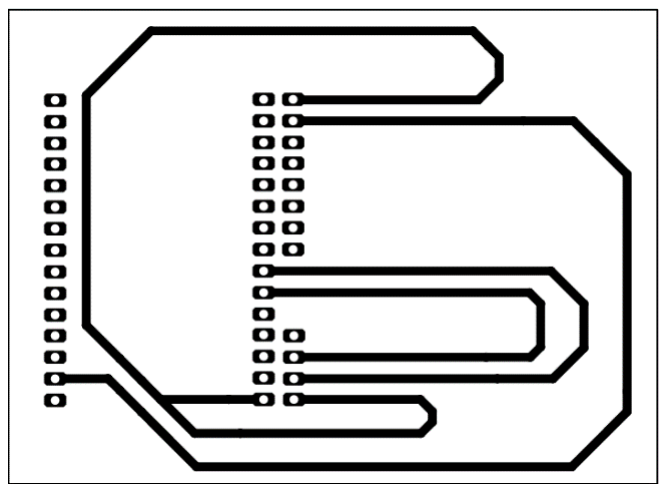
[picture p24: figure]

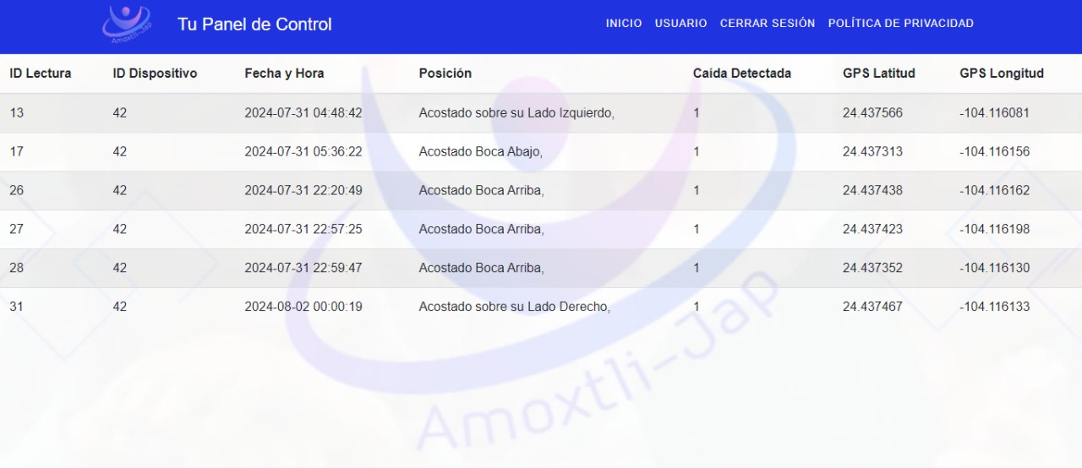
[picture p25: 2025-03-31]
Innova TecNM 2024 Etapa Regional/Página Web/img/portfolio/panel_de_control.jpg

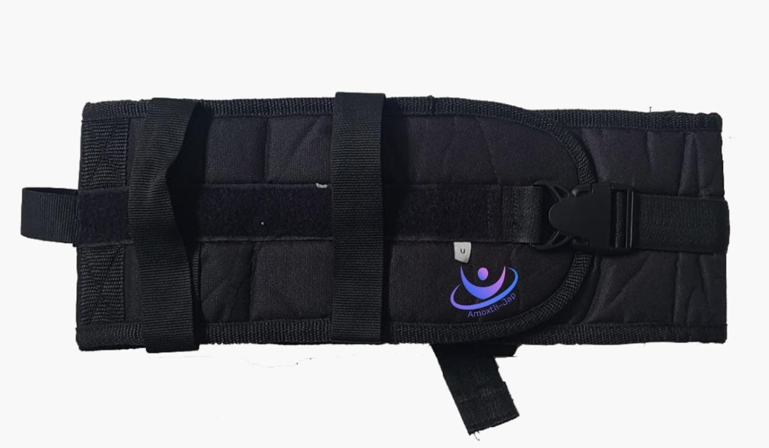
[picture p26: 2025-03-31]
Innova TecNM 2024 Etapa Regional/Página Web/img/portfolio/Cinturon_solo.jpg

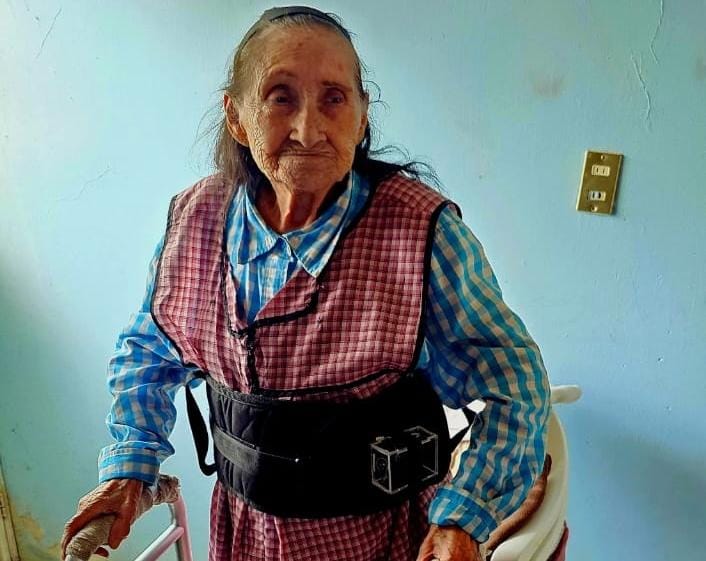
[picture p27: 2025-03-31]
Innova TecNM 2024 Etapa Regional/Página Web/img/portfolio/Cinturon_puesto.jpg

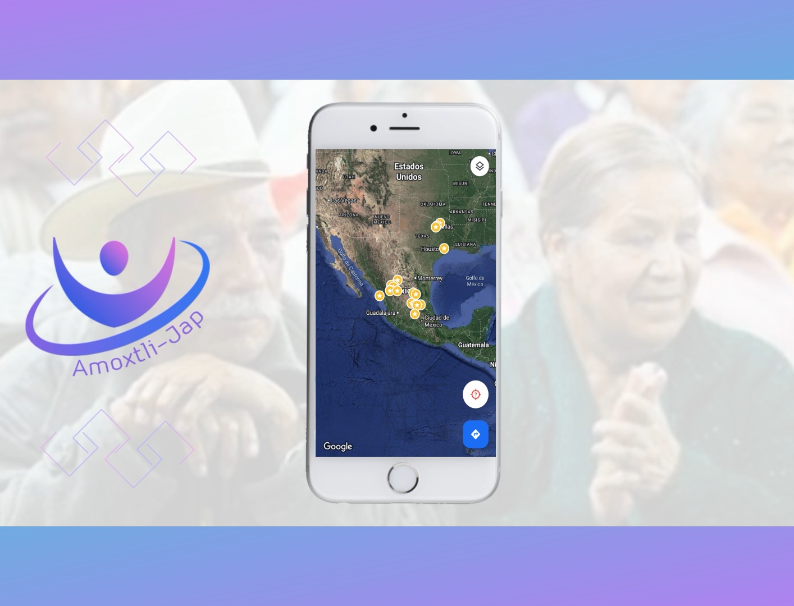
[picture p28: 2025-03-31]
Innova TecNM 2024 Etapa Regional/Página Web/img/portfolio/Mapa.jpg

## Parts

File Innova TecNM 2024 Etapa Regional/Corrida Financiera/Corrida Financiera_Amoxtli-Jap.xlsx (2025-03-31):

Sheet: Presentacion
Nombre del proyecto | Amoxtli-Jap
Descripcion del proyecto | Cinturon auxiliar para monitoreo de alerta para la deteccion de caidas en adultos mayores
Logotipo del proyecto
Slogan | La seguridad de tu familia, el corazon de nuestra tecnologia
Integrantes del equipos del proyecto | Bryam Muñiz, Gabriel Carrizales, Carmen Hernandez, Miguel Rodriguez y Abril Sanchez

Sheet: Inversion
Amoxtli-Jap
AREA | TIPO DE ACTIVO | CANTIDAD | ACTIVO | DESCRIPCION DEL ACTIVO | PRECIO UNITARIO | TOTAL
Produccion | Maquinaria | 1 | Fresadoras CNC | CNCTOPBAOS 1610 PRO Mini kit de enrutador CNC, 3 ejes de computadora GRBL Control DIY máquina de grabado, grabado grabado en acrílico, PVC, PCB, plástico, fresadora de corte de madera | $2800.00 | $2800.00
 |  | 1 | estacion de soldadura | Marca: LRT, Peso del producto: 5.3 libras, Voltaje: 110 voltios, Vataje: 700 watts, tipo de pantalla: LED, Para soldar y desoldar SMD. Aire caliente suave y giratorio, Aplicable a cables planos y conectores de cable. | $1181.00 | $1181.00
 |  | 1 | Impresora 3D | Nombre: K6 plus, Tampaño: 100*100*100mm, metodo de impresión: PLA | $3099.00 | $3099.00
 | Mobiliario y equipo | 1 | Multimetro | Tensión, resistencia, continuidad, capacitancia.Terminal de entrada para mediciones de corriente CA y CC hasta 10 A y corriente.Pantalla retroiluminada. Retencion de datos. Prueba de diosos, mas mediciones de frecuencia y ciclo de trabajo.La precisión se especifica durante 1 año después de la calibración, a temperaturas de funcionamiento de 18 ° C a 28 ° C, humedad relativa de 0% a 75%. Las especificaciones de precisión toman la forma de: ± ([% de lectura] + [Número de dígitos menos significativos]) | $799.00 | $799.00
 |  | 1 | atril para soldar | Es una estación de lupa de mano iluminada con una lente auxiliar de 3X de 3 pulgadas, y lentes auxiliares de 4.5X y 25X.Con espacio de almacenamiento, se puede almacenar en el mantenimiento del proceso de soldadura necesario para atornillar y otras piezas pequeñas. | $340.00 | $340.00
 |  | 1 | extractor |  | $90.00 | $90.00
 |  | 2 | pasta para soldar | Pasta para soldar fabricada a base de petrolato.Alta resistencia.Anticorrosiva, libre de plomo e insoluble al agua. No deteriora las superficies a soldar. Ayuda a la distribucion de soldadura | $30.00 | $60.00
 |  | 2 | rollo de estaño | Este tipo de material lo puedes emplear en las uniones de diversos sistemas como lo son las soldaduras de circuitos electrónicos, las aleaciones 63Sn, el recubrimiento de algunos metales, aplicaciones del área eléctrica y ensamblado de diversas partes de sistemas combinados. Esta aleación 60 % de estaño y 40 % de plomo se usa en este tipo de aplicaciones porque su temperatura de fusión es relativamente baja (cerca de 190 ºC).Contiene 100 gramos para que puedas realizar un alto número de soldaduras con un solo paquete. | $125.00 | $250.00
 |  | 1 | Puntas de cautin | Marca: BAKU,Modelo: BK-9033, Puntas para cautin de repuesto paquete de 4 piezas, Contiene 4 piezas de repuesto | $150.00 | $150.00
 |  | 1 | Cautin | Cautín Lápiz 40/60 W. Con Selector De Temperatura Alta/baja Cautín eléctrico tipo lápiz con punta cónica niquelada y plateada. Con potencia de 40/60 W, Frecuencia: 60 HZ. Con selector de temperatura alta/baja, ideal para estudiantes principiantes. Excelente para trabajos eléctricos, cables, conexiones de bocinas, soldaduras en kits, cables, televisiones, trabajos electrónicos, etc. 110 V. | $185.00 | $185.00
 |  | 3 | Mesas de produccion |  | $600.00 | $1800.00
 | Gastos de intalacion | 2 | Extintor | Tipo de matafuego: Tradicional, Capacidad: 9 Kg, Apto para autos y es recargable incluye soporte y baliza | $1268.00 | $2536.00
 |  | 3 | Ungüento para quemaduras |  | $41.00 | $123.00
 |  | 7 | Lentes de proteccion | Lentes de seguridad transparente surtek, fabricados en policarbonato, para aplicaciones en condiciones de luz normal, marca surtek, color transparente, material: Policarbonato | $58.00 | $406.00
 |  | 7 | Taloneras antiestatica | La composición de la Talonera es 35% Caucho, 35% SBR, 5% Fibra de Carbon, 25% Poliester.Confeccion de alta calidad con costuras fuertes.Ofrece una resistencia 10^5 OHMS.Unitalla, Presentación: Una Pieza y Facil de usar | $99.00 | $693.00
 |  | 1 | Botiquin de primeros auxilios | Gran capacidad. El compartimento principal tiene 6 bolsas de malla, adecuadas para llevar suministros como gasas, contenedores de pérdida de emergencia, estetoscopios, vendajes, etc.Organizar sus necesidades médicas de forma ordenada y ordenada. | $549.00 | $549.00
Ventas | Mobiliario y equipo | 1 | Escritorio | Ancho: 120 cm, Profundidad: 50 cm, Largo: 120 cm,Altura: 72 cm, Forma de L., Compuesto de mdf, 2 estantes. Pesa 23kg., Requiere ensamblado., Ideal para leer, escribir o usar la PC. | $1180.00 | $1180.00
 |  | 1 | Silla | Silla Secretarial metálica / Con acabados en color blanco / Incluye base de estrella con 5 llantas / Revestida en tela verde / Elevador de gas de 100 mm / Mecanismo de subida y bajada / Base metálica de 260 mm / Ruedas de nylon | $591.00 | $591.00
 | Equipos de computo | 1 | Impresora termica | Modelo: NT-8330, Comando de impresión: esc/pos, impresión termica en lineas, velocidad de impresión: 220mm/s, cortador de papel automatico, ancho de impresión: 72mm, tipo de papel: rollo, color: blanco y negro. | $1295.00 | $1295.00
 |  | 1 | Computadora | PC de computadora HP eliete 6200 de factor de forma pequeño, intel quad core i5-2400 hasta 3,4 GHz, 8G DDR3, 1T, DVDRW,WiFi, windowa 1064- Soporte multilingue. Incluye: Teclado y mouse USB, adaptador WiFi. | $3200.00 | $3200.00
 | Gastos de intalacion | 1 | Pintura | Realizar un acondicionamiento del local mediante la remodelación con ayuda de pintura para hacerlo más cómodo y atractivo para los clientes. | $3000.00 | $3000.00
 |  | 1 | Aire acondicionado | Marca Generic, Capacidad 3,25 Libras, Potencia de refrigeración 1,14 Kilowatts, Característica especial Ajustable, Función de calefacción y refrigeración, Dimensiones del producto 12prof. x 42an. x 18alt. centimeters, Energy Star 3 Star Año de inicio 2024, Color Blanco, Voltaje 110 Voltios, Nivel de ruido 45 d | $961.00 | $961.00
Administracion | Mobiliario y equipo | 5 | Escritorio | Ancho: 120 cm, Profundidad: 50 cm, Largo: 120 cm,Altura: 72 cm, Forma de L., Compuesto de mdf, 2 estantes. Pesa 23kg., Requiere ensamblado., Ideal para leer, escribir o usar la PC. | $1180.00 | $5900.00
 |  | 10 | Sillas de oficina | Mantente en movimiento, Las ruedas te van a permitir moverte y limpiar fácilmente tu espacio. Podrás trasladarla sin dificultad cuando lo necesites. Además, al ser giratoria te permitirá rotar el asiento 360º sin la necesidad de cambiar de posición o moverte del lugar en donde estás. Peso de la silla : 6,400kg, Peso máximo recomendado : 90 - 100kg, Altura Ajustable Max: 52 cm, Altura Ajustable Min: 42 cm, Asiento Giratorio 360°, Ruedas Giratorios 360° Distancia del Piso al Respaldo: 92cm Max. / 82cm Mínimo. Peso y dimensiones Altura mínima del piso al asiento 42 cm, Altura máxima del piso al asiento 52 cm, Altura mínima de la silla 82 cm, Altura máxima de la silla 92 cm | $591.00 | $5910.00
 | Equipos de computo | 1 | Impresora | Inyeccion termica de tinta HP, Impresión, copia y escaneado, conexiones: wi-fi, usb de alta velocidad,7.5 ppm, dimension del producto: 425*304*154 mm, | $1295.00 | $1295.00
 |  | 3 | Telefonos |  | $320.00 | $960.00
 |  | 5 | Computadora | PC de computadora HP eliete 6200 de factor de forma pequeño, intel quad core i5-2400 hasta 3,4 GHz, 8G DDR3, 1T, DVDRW,WiFi, windowa 1064- Soporte multilingue. Incluye: Teclado y mouse USB, adaptador WiFi. | $3200.00 | $16000.00
 | Gastos de intalacion | 1 | Pintura | Realizar un acondicionamiento del local mediante la remodelación con ayuda de pintura para hacerlo más cómodo y atractivo para los clientes. | $3000.00 | $3000.00
 |  | 1 | Aire acondicionado | Marca Generic, Capacidad 3,25 Libras, Potencia de refrigeración 1,14 Kilowatts, Característica especial Ajustable, Función de calefacción y refrigeración, Dimensiones del producto 12prof. x 42an. x 18alt. centimeters, Energy Star 3 Star Año de inicio 2024, Color Blanco, Voltaje 110 Voltios, Nivel de ruido 45 d | $961.00 | $961.00
 | Total |  |  |  |  | $59314.00
 | Capital de trabajo |  |  |  |  | $738379.84
 | Inversion total |  |  |  |  | $797693.84

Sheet: Depreciaciones
Amoxtli-jap
Calculo de las depreciaciones
Area | Cantidad | Activo | Porcentaje de depreciacion | Año | Monto original de la inversion | Vida util en años | Depreciacion anual | Año 1 | Año 2 | Año 3 | Año 4 | Año 5
Produccion |  | Maquinaria |  |  |  |  | $708.00 | $708.00 | $708.00 | $708.00 | $708.00 | $708.00
 | 1 | Fresadora CNC | 10% | 1 | $2800.00 | 20 | $280.00 | $280.00 | $280.00 | $280.00 | $280.00 | $280.00
 | 1 | Estacion de soldadura | 10% | 1 | $1181.00 | 20 | $118.10 | $118.10 | $118.10 | $118.10 | $118.10 | $118.10
 | 1 | Impresora 3D | 10% | 1 | $3099.00 | 20 | $309.90 | $309.90 | $309.90 | $309.90 | $309.90 | $309.90
 |  | Mobiliario y equipo |  |  |  |  | $60.00 | $300.00 | $300.00 | $300.00 | $300.00 | $300.00
 | 5 | Mesas de produccion | 10% | 1 | $600.00 | 10 | $60.00 | $300.00 | $300.00 | $300.00 | $300.00 | $300.00
Ventas |  | Mobiliario y equipo |  |  |  |  | $177.10 | $177.10 | $177.10 | $177.10 | $177.10 | $177.10
 | 1 | Escritorio | 10% | 1 | $1180.00 | 10 | $118.00 | $118.00 | $118.00 | $118.00 | $118.00 | $118.00
 | 1 | Silla | 10% | 1 | $591.00 | 10 | $59.10 | $59.10 | $59.10 | $59.10 | $59.10 | $59.10
 |  | Equipo de computo |  |  |  |  | $1498.18 | $1498.18 | $1498.18 | $1498.18 | $0.00 | $0.00
 | 1 | Impresora | 33.33% | 1 | $1295.00 | 3 | $431.62 | $431.62 | $431.62 | $431.62 | $0.00 | $0.00
 | 1 | Computadora | 33.33% | 1 | $3200.00 | 3 | $1066.56 | $1066.56 | $1066.56 | $1066.56 | $0.00 | $0.00
Administracion |  | Mobiliario y equipo |  |  |  |  | $177.10 | $1181.00 | $1181.00 | $1181.00 | $1181.00 | $1181.00
 | 5 | Escritorio | 10.00% | 1 | $1180.00 | 10 | $118.00 | $590.00 | $590.00 | $590.00 | $590.00 | $590.00
 | 10 | Silla de oficina | 10.00% | 1 | $591.00 | 10 | $59.10 | $591.00 | $591.00 | $591.00 | $591.00 | $591.00
 |  | Equipo de computo |  |  |  |  | $1498.18 | $5764.42 | $5764.42 | $5764.42 | $0.00 | $0.00
 | 1 | Impresora | 33.33% | 1 | $1295.00 | 3 | $431.62 | $431.62 | $431.62 | $431.62
 | 5 | computadora | 33.33% | 1 | $3200.00 | 3 | $1066.56 | $5332.80 | $5332.80 | $5332.80
 |  |  |  |  |  |  |  | $9628.71 | $9628.71 | $9628.71 | $2366.10 | $2366.10

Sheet: Costos
Amoxtli-Jap
Materia prima
Concepto | Cantidad a usar para 1 cinturon | Costo por pieza | costo total por producir 1 cinturon | estimacion de produccion mensual (u) | costo total estimado mensual 1u de cinturon | Costo total estimado mensual 132 unidades de cinturon | Capital de trabajo por 3 meses | costo anual
Microcontrolador ESP32 | 1 | $200.00 | $200.00 | 94 | $200.00 | $18800.00 | $56400.00 | $225600.00
Acelerometro (Giroscopio MPU6050) | 1 | $89.000 | $89.00 | 94 | $89.00 | $8366.00 | $25098.00 | $100392.00
GPS NEO-6M | 1 | $159.000 | $159.00 | 94 | $159.00 | $14946.00 | $44838.00 | $179352.00
Buzzer | 1 | $15.000 | $15.00 | 94 | $15.00 | $1410.00 | $4230.00 | $16920.00
Push Button (50*70mm) | 1 | $3.000 | $3.00 | 94 | $3.00 | $282.00 | $846.00 | $3384.00
Bateria recargable | 3 | $299.000 | $897.00 | 94 | $897.00 | $84318.00 | $252954.00 | $1011816.00
Porta pilas | 1 | $9.000 | $9.00 | 94 | $9.00 | $846.00 | $2538.00 | $10152.00
Placa fenolica PCB | 1 | $19.000 | $19.00 | 94 | $19.00 | $1786.00 | $5358.00 | $21432.00
Cinturon | 1 | $500.000 | $500.00 | 94 | $500.00 | $47000.00 | $141000.00 | $564000.00
 | peso en kilo
Rollo de filamento PLA | 0.04 | $15.960 | $0.64 | 94 | $0.64 | $60.01 | $180.03 | $720.12
Total |  | $1308.96 | $1891.64 |  | $1891.64 | $177814.01 | $533442.03 | $2133768.12
Mano de obra (24 dias trabajados)
Cantidad | Trabajador | Chalecos fabricadas por dia | sueldo diario | sueldo mensual | capital de trabajo por 3 meses | Capital de trabajo anual
1 | Operador | 5.5 | $248.93 | $7467.90 | $22403.70 | $89614.80
1 | Operador | 5.5 | $248.93 | $7467.90 | $22403.70 | $89614.80
1 | Operador | 5.5 | $248.93 | $7467.90 | $22403.70 | $89614.80
1 | Encargado de laboratorios | 5.5 | $400.00 | $12000.00 | $36000.00 | $144000.00
1 | Encargado de produccion | 5.5 | $500.00 | $15000.00 | $45000.00 | $180000.00
Total |  |  | $1646.79 | $49403.70 | $148211.10 | $592844.40
Gastos de fabricacion o indirectos
Concepto | costo total mensual | capital de trabajo de 3 meses | costo anual
Luz | $1000.00 | $3000.00 | $12000.00
Internet | $133.33 | $400.00 | $1600.00
Agua | $500.00 | $1500.00 | $6000.00
Depreciacion de mobiliario y equipo | $25.00 | $75.00 | $300.00
Depreciacion de maquinaria | $59.00 | $177.00 | $708.00
Local renta | $2666.67 | $8000.00 | $32000.00
total | $4384.00 | $13152.00 | $52608.00
Concentrado
Costos de produccion | Costo total mensual | Capital de trabajo a 3 meses | costo anual
Materia prima | $177814.01 | $533442.03 | $2133768.12
Mano de obra | $49403.70 | $148211.10 | $592844.40
Gastos indirectos | $4384.00 | $13152.00 | $52608.00
Total | $231601.71 | $694805.13 | $2779220.52
Costo unitario
Produccion anual de cinturones | costos anuales | costo por cinturon anual
1128 | $2779220.52 | $2463.85

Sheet: Ingresos
Amoxtli-Jap
Estimacion de los ingresos del proyecto basados en resultados del estudio de mercado y tecnico
tipo de producto | cinturon/ Chalecos a vender por mes | precio de venta | ingresos mensuales | ingresos anuales | Criterios para tomar en cuenta el precio
Cinturon auxiliar para monitoreo de alerta en adultos mayores | 94 | $3326.19 | $312662.31 | $3751947.70 | costo unitario | $2463.85
 |  |  |  |  | margen de utilidad | $862.35
 |  |  |  |  | precio de productos sustitutos | $4499.00
 |  |  |  |  | precio total final | $3326.19

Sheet: Gastos
Amoxtli-Jap
Gastos de venta
concepto | costo mensual | capital de trabajo de 3 meses | costo anual
Publicidad digital | $306.00 | $918.00 | $3672.00
renta | $2666.67 | $8000.00 | $32000.00
servicios | $1633.33 | $4900.00 | $19600.00
depreciacion de mobiliario | $14.76 | $44.27 | $177.10
depreciacion de equipo de computo | $124.85 | $374.55 | $1498.18
total gastos de venta | $4745.61 | $14236.82 | $56947.28
Prestaciones laborales de ley
Concepto | mensual | 3 meses | anual
15 dias de aguinaldo | $2058.49 | $6175.46 | $24701.85
25% de prima de vacacional | $411.70 | $1235.09 | $4940.37
Prima dominical 25% |  |  |  | Solo si abre el domingo
Tiempo extra
PTU
IMMS | $3904.87 | $11714.61 | $46858.42
INFONAVIT | $2503.12 | $7509.36 | $30037.45
SISTEMA DE AHORRO PARA EL RETIRO (SAR) | $901.12 | $2703.37 | $10813.48
Total de prestaciones de ley | $9779.30 | $29337.89 | $117351.57
Total de gastos de operación | $14524.90 | $43574.71 | $174298.86
Desgloce de prestaciones laborales
Trabajadores | Salario diario | Aguinaldo | Dias de vacaciones | Sueldo de vacaciones | Prima vacacional 25% | IMSS 8% | INFONAVIT 5% | SAR 1.8%
Operador | $248.93 | $3733.95 | 12 | $2987.16 | $746.79 | $590.26 | $378.37 | $136.21
Operador | $248.93 | $3733.95 | 12 | $2987.16 | $746.79 | $590.26 | $378.37 | $136.21
Operador | $248.93 | $3733.95 | 12 | $2987.16 | $746.79 | $590.26 | $378.37 | $136.21
Encargado de laboratorios | $400.00 | $6000.00 | 12 | $4800.00 | $1200.00 | $948.48 | $608.00 | $218.88
Encargado de produccion | $500.00 | $7500.00 | 12 | $6000.00 | $1500.00 | $1185.60 | $760.00 | $273.60
Total de prestaciones |  | $24701.85 |  |  | $4940.37 | $3904.87 | $2503.12 | $901.12

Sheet: Estructura de capital
Amoxtli-Jap
Estructura de capital
Inversion total | 797693.8429 | $797693.84
Capital propio
socios |  |  | Financiamiento | Monto | Tasa de interes | Plazo
Bryam | $40000.00 |  | Programa financiero para emprendedores | $500000.00 | 13.00% | 48 meses
Gabriel | $40000.00 |  | Crowfunding | $52306.16 | 3.00% | 36 meses
Carmen | $40000.00
Miguel | $40000.00
Abril | $40000.00
Mama de bryam | $30000.00
Mama de gabriel | $30000.00
Mama de carmen | $30000.00
Mama de miguel | $30000.00
Mama de abril | $30000.00
total | $350000.00
 | $447693.84

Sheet: Tabla de amortizacion
Amoxtli-Jap
Programa financiero para emprendedores
 | Importe del prestamo | $500000.00
 | Plazo | 4 años | 48
 | tipo de pago | Menusal
 | tipo de interes anual | 13.00%
 | importe de pago mensual | $13413.75
Mes | Amortizacion | Interes | Abono o capital | saldo insoluto |  | Datos
0 |  |  |  | $500000.00 |  | Prestamo | $500000.00
1 | $7997.08 | $5416.67 | $13413.75 | $492002.92 |  | Tasa mensual | 1.08%
2 | $8083.72 | $5330.03 | $13413.75 | $483919.20 |  | Plazo, meses | 48
3 | $8171.29 | $5242.46 | $13413.75 | $475747.91 |  | Anualidad | $13413.75
4 | $8259.81 | $5153.94 | $13413.75 | $467488.10
5 | $8349.29 | $5064.45 | $13413.75 | $459138.81
6 | $8439.74 | $4974.00 | $13413.75 | $450699.06
7 | $8531.17 | $4882.57 | $13413.75 | $442167.89
8 | $8623.60 | $4790.15 | $13413.75 | $433544.29
9 | $8717.02 | $4696.73 | $13413.75 | $424827.27
10 | $8811.45 | $4602.30 | $13413.75 | $416015.82
11 | $8906.91 | $4506.84 | $13413.75 | $407108.91
12 | $9003.40 | $4410.35 | $13413.75 | $398105.51 | $59070.49
13 | $9100.94 | $4312.81 | $13413.75 | $389004.57
14 | $9199.53 | $4214.22 | $13413.75 | $379805.04
15 | $9299.19 | $4114.55 | $13413.75 | $370505.85
16 | $9399.93 | $4013.81 | $13413.75 | $361105.91
17 | $9501.77 | $3911.98 | $13413.75 | $351604.14
18 | $9604.70 | $3809.04 | $13413.75 | $341999.44
19 | $9708.75 | $3704.99 | $13413.75 | $332290.69
20 | $9813.93 | $3599.82 | $13413.75 | $322476.76
21 | $9920.25 | $3493.50 | $13413.75 | $312556.51
22 | $10027.72 | $3386.03 | $13413.75 | $302528.79
23 | $10136.35 | $3277.40 | $13413.75 | $292392.43
24 | $10246.16 | $3167.58 | $13413.75 | $282146.27 | $45005.74
25 | $10357.16 | $3056.58 | $13413.75 | $271789.11
26 | $10469.37 | $2944.38 | $13413.75 | $261319.74
27 | $10582.78 | $2830.96 | $13413.75 | $250736.96
28 | $10697.43 | $2716.32 | $13413.75 | $240039.53
29 | $10813.32 | $2600.43 | $13413.75 | $229226.21
30 | $10930.46 | $2483.28 | $13413.75 | $218295.74
31 | $11048.88 | $2364.87 | $13413.75 | $207246.87
32 | $11168.57 | $2245.17 | $13413.75 | $196078.29
33 | $11289.57 | $2124.18 | $13413.75 | $184788.73
34 | $11411.87 | $2001.88 | $13413.75 | $173376.86
35 | $11535.50 | $1878.25 | $13413.75 | $161841.36
36 | $11660.47 | $1753.28 | $13413.75 | $150180.89 | $28999.59
37 | $11786.79 | $1626.96 | $13413.75 | $138394.10
38 | $11914.48 | $1499.27 | $13413.75 | $126479.62
39 | $12043.55 | $1370.20 | $13413.75 | $114436.07
40 | $12174.02 | $1239.72 | $13413.75 | $102262.05
41 | $12305.91 | $1107.84 | $13413.75 | $89956.14
42 | $12439.22 | $974.52 | $13413.75 | $77516.91
43 | $12573.98 | $839.77 | $13413.75 | $64942.93
44 | $12710.20 | $703.55 | $13413.75 | $52232.73
45 | $12847.89 | $565.85 | $13413.75 | $39384.84
46 | $12987.08 | $426.67 | $13413.75 | $26397.76
47 | $13127.77 | $285.98 | $13413.75 | $13269.99
48 | $13269.99 | $143.76 | $13413.75 | $2.273736754e-10 | $10784.09
Credito Banorte
 | Importe del prestamo | $52306.16
 | Plazo | 3 años | 36
 | tipo de pago | Menusal
 | tipo de interes anual | 3.00%
 | importe de pago mensual | $1521.13
Mes | Amortizacion | Interes | Abono o capital | saldo insoluto |  | Datos
0 |  |  |  | $52306.16 |  | Prestamo | $52306.16
1 | $1390.36 | $130.77 | $1521.13 | $50915.80 |  | Tasa mensual | 0.25%
2 | $1393.84 | $127.29 | $1521.13 | $49521.96 |  | Plazo, meses | 36
3 | $1397.32 | $123.80 | $1521.13 | $48124.64 |  | Anualidad | $1521.13
4 | $1400.81 | $120.31 | $1521.13 | $46723.82
5 | $1404.32 | $116.81 | $1521.13 | $45319.51
6 | $1407.83 | $113.30 | $1521.13 | $43911.68
7 | $1411.35 | $109.78 | $1521.13 | $42500.33
8 | $1414.88 | $106.25 | $1521.13 | $41085.46
9 | $1418.41 | $102.71 | $1521.13 | $39667.04
10 | $1421.96 | $99.17 | $1521.13 | $38245.08
11 | $1425.51 | $95.61 | $1521.13 | $36819.57
12 | $1429.08 | $92.05 | $1521.13 | $35390.49 | $1337.85
13 | $1432.65 | $88.48 | $1521.13 | $33957.84
14 | $1436.23 | $84.89 | $1521.13 | $32521.61
15 | $1439.82 | $81.30 | $1521.13 | $31081.79
16 | $1443.42 | $77.70 | $1521.13 | $29638.37
17 | $1447.03 | $74.10 | $1521.13 | $28191.34
18 | $1450.65 | $70.48 | $1521.13 | $26740.69
19 | $1454.27 | $66.85 | $1521.13 | $25286.41
20 | $1457.91 | $63.22 | $1521.13 | $23828.50
21 | $1461.56 | $59.57 | $1521.13 | $22366.95
22 | $1465.21 | $55.92 | $1521.13 | $20901.74
23 | $1468.87 | $52.25 | $1521.13 | $19432.87
24 | $1472.54 | $48.58 | $1521.13 | $17960.32 | $823.35
25 | $1476.23 | $44.90 | $1521.13 | $16484.10
26 | $1479.92 | $41.21 | $1521.13 | $15004.18
27 | $1483.62 | $37.51 | $1521.13 | $13520.57
28 | $1487.32 | $33.80 | $1521.13 | $12033.24
29 | $1491.04 | $30.08 | $1521.13 | $10542.20
30 | $1494.77 | $26.36 | $1521.13 | $9047.43
31 | $1498.51 | $22.62 | $1521.13 | $7548.92
32 | $1502.25 | $18.87 | $1521.13 | $6046.67
33 | $1506.01 | $15.12 | $1521.13 | $4540.66
34 | $1509.77 | $11.35 | $1521.13 | $3030.88
35 | $1513.55 | $7.58 | $1521.13 | $1517.33
36 | $1517.33 | $3.79 | $1521.13 | $1.023181539e-11 | $2454.39

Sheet: Punto de equilibrio
Amoxtli-Jap
Credito Solidario
Costos fijos | año 1
mano de obra | $592844.40
gastos indirectos | $40608.00
gastos de venta | $56947.28
prestaciones laborales | $117351.57
total | $807751.26
costos variables | año 1
materia prima | $2133768.12
gastos indirectos | $12000.00
total | $2145768.12
costos totales | $2953519.37
Precio de venta por unidad | $3326.19
costos fijos totales | $807751.26
costos variables por unidad | $1902.28
margen de contribucion | $1423.92
P.E en unidades | $567.27
P.E en ventas | $1886862.78

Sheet: Estado de resultados
Amoxtli-Jap
 | AÑO 1 | AÑO 2 | AÑO 3 | AÑO 4 | AÑO 5
ingresos | $3751947.70 | $3925662.87 | $4107421.06 | $4297594.66 | $4496573.29 | Indice de inflacion 4.63%
costo de produccion | $2779220.52 | $2907898.43 | $3042534.12 | $3183403.45 | $3330795.03
Materia prima | $2133768.12 | $2232561.58 | $2335929.18 | $2444082.70 | $2557243.73
Mano de obra | $592844.40 | $620293.10 | $649012.67 | $679061.95 | $710502.52
gastos indirectos | $52608.00 | $55043.75 | $57592.28 | $60258.80 | $63048.78
depreciacion
utilidad bruta | $972727.18 | $1017764.45 | $1064886.94 | $1114191.21 | $1165778.26
gastos de operación | $174298.86 | $182368.89 | $190812.57 | $199647.20 | $208890.86
gastos de venta | $56947.28 | $59583.94 | $62342.68 | $65229.15 | $68249.25
prestaciones laborales | $117351.57 | $122784.95 | $128469.89 | $134418.05 | $140641.61
utilidad de operación | $798428.32 | $835395.56 | $874074.37 | $914544.01 | $956887.40
gastos financieros | $60408.34 | $45829.08 | $31453.98 | $10784.09 | $0.00
Utilidad antes de impuestos | $738019.99 | $789566.47 | $842620.38 | $903759.93 | $956887.40
PTU 10% | $73802.00 | $78956.65 | $84262.04 | $90375.99 | $95688.74
ISR 28% | $206645.60 | $221078.61 | $235933.71 | $253052.78 | $267928.47
Utilidad neta del ejercicio | $457572.39 | $489531.21 | $522424.64 | $560331.16 | $593270.19

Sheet: Flujo de efectivo
Amoxtli-Jap
Flujo de efectivo proyectado
Concepto | Año 0 | Año 1 | Año 2 | Año 3 | Año 4 | Año 5
(+) Ventas | $0.00 | $3751947.70 | $3925662.87 | $4107421.06 | $4297594.66 | $4496573.29
(+) Valor de rescate | $0.00 | $0.00 | $0.00 | $0.00 | $0.00 | $0.00
(=) Inresos totales | $0.00 | $3751947.70 | $3925662.87 | $4107421.06 | $4297594.66 | $4496573.29
Costos de produccion | $0.00 | $2779220.52 | $2907898.43 | $3042534.12 | $3183403.45 | $3330795.03
Gastos de operación | $0.00 | $174298.86 | $182368.89 | $190812.57 | $199647.20 | $208890.86
Gastos financieros | $0.00 | $60408.34 | $45829.08 | $31453.98 | $10784.09 | $0.00
(=) Costos totales | $0.00 | $3013927.71 | $3136096.40 | $3264800.68 | $3393834.73 | $3539685.89
Compra activo fijo | $55353.00 | $0.00 | $0.00 | $0.00 | $0.00 | $0.00
Compra activo diferido | $3961.00 | $0.00 | $0.00 | $0.00 | $0.00 | $0.00
Compra capital de trabajo | $738379.84 | $0.00 | $0.00 | $0.00 | $0.00 | $0.00
(=) Saldo final | -$797693.84 | $738019.99 | $789566.47 | $842620.38 | $903759.93 | $956887.40
Flujos de efectivo | Año 1 | Año 2 | Año 3 | Año 4 | Año 5
Utilidad neta del ejercicio | $457572.39 | $489531.21 | $522424.64 | $560331.16 | $593270.19
(+) Depreciacion | $9628.71 | $9628.71 | $9628.71 | $2366.10 | $2366.10
Subtotal | $467201.10 | $499159.92 | $532053.35 | $562697.26 | $595636.29
(+)VALOR DE RESCATE | 0 | 0 | 0 | 0 | 0
Flujo de efectivo anual | $467201.10 | $499159.92 | $532053.35 | $562697.26 | $595636.29

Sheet: Balance general
Amoxtli-Jap
Balance general proyectado a cinco años
 | Año 1 | Año 2 | Año 3 | Año 4 | Año 5
Activo
Activo circulante
Bancos | $41031.10 | $17673.35 | $18870.24 | $16330.67 | $8799.48
Inventario | $60900.00 | $36000.00 | $36090.00 | $37060.00 | $46000.00
Total Circulante | $101931.10 | $53673.35 | $54960.24 | $53390.67 | $54799.48
Fijo
Maq. Y equipo | $7080.00 | $7080.00 | $7080.00 | $7080.00 | $7080.00
Depreciacion | $708.00 | $708.00 | $708.00 | $708.00 | $708.00
Mobiliario | $15381.00 | $15381.00 | $15381.00 | $15381.00 | $15381.00
Depreciacion | $1658.10 | $1658.10 | $1658.10 | $1658.10 | $1658.10
Eq. De computo | $22750.00 | $22750.00 | $22750.00 | $22750.00 | $22750.00
Depreciacion | $7262.61 | $7262.61 | $7262.61 | $0.00 | $0.00
Total fijo | $35582.29 | $35582.29 | $35582.29 | $42844.90 | $42844.90
Diferido
Gastos de instalacion | $3961.00 | $3961.00 | $3961.00 | $3961.00 | $3961.00
Total diferido | $3961.00 | $3961.00 | $3961.00 | $3961.00 | $3961.00
total activo | $141474.39 | $93216.64 | $94503.53 | $100196.57 | $101605.38
Pasivo
Circulante
Sueldos, deudores, imp.
Prestamos a corto plazo | $552306.16 | 0 | 0 | 0 | 0
Total Circulante | $552306.16 | $0.00 | $0.00 | $0.00 | $0.00
Total pasivo | $552306.16 | $0.00 | $0.00 | $0.00 | $0.00
Capital contable
Capital social | $350000.00 | $350000.00 | $350000.00 | $350000.00 | $350000.00
Utilidad del ejercicio | $457572.39 | $489531.21 | $522424.64 | $560331.16 | $593270.19
Total capital | $807572.39 | $839531.21 | $872424.64 | $910331.16 | $943270.19
Pasivo+capital | $1359878.55 | $839531.21 | $872424.64 | $910331.16 | $943270.19

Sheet: Indicadores financieros
Amoxtli-Jap
Analisis de indicadores financieros
Flujos de efectivo | Año 1 | Año 2 | Año 3 | Año 4 | Año 5 |  | Periodo de recuperacion
-$797693.84 | $738019.99 | $789566.47 | $842620.38 | $903759.93 | $956887.40 |  |  | inversion/ flujo | Ingreso acumulado
 |  |  |  |  |  |  | 0 | -$797693.84 | -$797693.84
Tasa de rendimiento el mercado | 11.35% |  |  |  |  |  | 1 | $467201.10 | -$330492.74
VPN | $1123835.71 |  |  |  |  |  | 2 | $499159.92 | $168667.18
 |  |  |  |  |  |  | 3 | $532053.35 | $700720.52
TIR | 56.56019578% |  |  |  |  |  | 4 | $562697.26 | $1263417.78
 |  |  |  |  |  |  | 5 | $595636.29 | $1859054.06
Periodo de recuperacion | Flujo mensual | $46891.44
 | Meses que se tarda en recuperar | 14.94346414 | La inversion se recupera en 3 años y 2 meses |  |  | Conclusiones
 | Flujo diario | $1541.64 |  |  |  | PRI: Como conclusion tras haber efectuado los calculos de los indicadores financieros correspondientes, obtenemos que el Periodo de Recuperacion de la Inversion es de 3 años y dos meses, periodo que se considera aceptable debido a que es menor al periodo de la vida util del proyecto, es decir, 3 años.
 | Dias en que se tarda en recuperar | 454.5303676 | La inversions se recupera en 3 años y 69 dias
 |  |  |  |  |  | VPN: En cuanto al Valor Presente Neto observamos que se obtiene un valor positivo que asciende a $15,442, hecho que sugiere que la empresa ganara valor a traves del tiempo
 |  |  |  |  |  | TIR: En lo referente a la Tasa Interna de Retorno, el porcentaje obtenido es del 17%, hecho que resulta beneficioso para el proyecto puesto que la tasa de rendimiento del mercado es igual al 11.35%, es decir, la TIR es mayor a dichatasa. De esto, podemos deducir que el proyecto generara mas rendimiento del que se espera.
 |  |  |  |  |  | General: Tras observar y analizar los diferentes indicadores financieros concluimos que resulta rentable invertir en el proyecto puesto que los resultados calculados parecen ser positivos.

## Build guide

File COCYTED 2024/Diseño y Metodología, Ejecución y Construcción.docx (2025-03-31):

Diseño y metodología

Planificación

La planificación comenzó con la conceptualización del diseño del cinturón/chaleco. Se definieron los objetivos del proyecto, que se centran en la elaboración de un dispositivo médico vestible especializado en proporcionar traslados seguros para las personas de la tercera edad o con movilidad reducida, optimizando la capacidad de respuesta ante eventos críticos y minimizando el riesgo de lesiones graves derivadas de caídas. Este dispositivo también tiene como meta brindar una mayor sensación de seguridad a los usuarios y sus familias, gracias a la implementación de sujetadores de alta resistencia que facilitan traslados por parte de cuidadores.

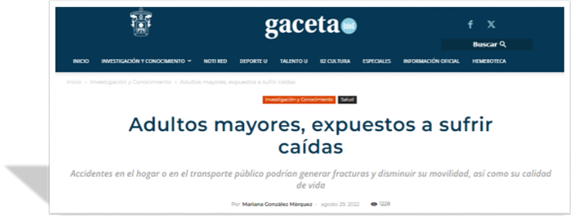
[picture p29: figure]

La elección de un cinturón o chaleco se basa en la necesidad de un diseño portátil, discreto, cómodo y práctico. Durante la fase de planificación, se realizó una investigación de mercado que reveló la creciente necesidad de dispositivos médicos vestibles, así como estadísticas sobre caídas en personas mayores que justifican este enfoque. Además, se llevó a cabo un análisis del perfil del usuario, considerando sus características y desafíos, para asegurar que el diseño se ajuste a sus necesidades.

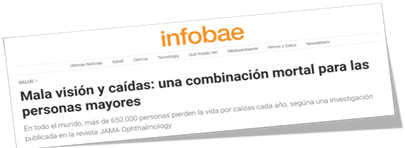
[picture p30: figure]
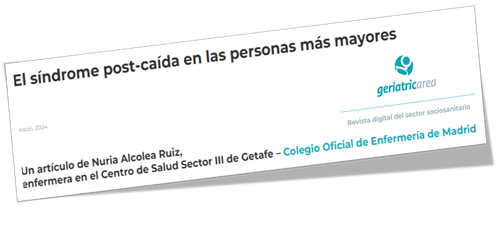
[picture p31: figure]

Las funcionalidades clave consideradas incluyen la detección automática de caídas, el envío de alertas a familiares o cuidadores y la localización GPS en tiempo real. También se exploró la posibilidad de colaborar con profesionales en el ámbito de la salud y el diseño de dispositivos médicos para garantizar la eficacia y seguridad del producto. En el largo plazo, se busca evolucionar el proyecto con la integración de funciones adicionales, basándose en la retroalimentación de los usuarios para mejorar constantemente la experiencia.

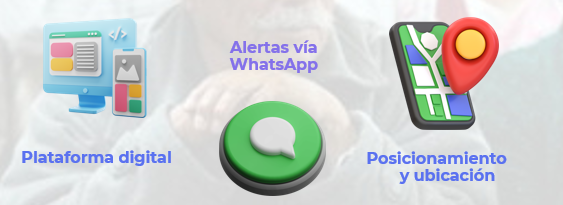
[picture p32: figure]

Selección de componentes

Para el desarrollo del prototipo en base a la planificación previa, se eligieron los materiales y sensores que componen el dispositivo, priorizando la eficiencia y funcionalidad. Los materiales y componentes seleccionados son:

Tela:

Se eligió una tela negra de alta resistencia y fácil de limpiar, que proporciona durabilidad y un aspecto discreto. Su textura suave garantiza comodidad durante el uso prolongado.

Velcro:

Utilizado para los sujetadores, permite un ajuste seguro y cómodo, facilitando la colocación y extracción del cinturón/chaleco.

Relleno de algodón:

Este material se incorporó para asegurar que el cinturón/chaleco sea cómodo y acolchado, reduciendo el riesgo de lesiones en caso de caídas.

Microcontrolador Esp32:

Elegido por su capacidad de procesamiento y conectividad Wi-Fi/Bluetooth, lo que permite la integración eficiente de los sensores y la comunicación de datos.

Geolocalizador GPS Neo-6m:

Este componente fue seleccionado por su alta precisión y fiabilidad en la localización, permitiendo rastrear la ubicación del usuario en tiempo real en caso de un incidente.

Giroscopio/acelerómetro MPU6050:

Seleccionado por su capacidad para detectar movimientos y caídas mediante sus tres ejes coordenados y su capacidad para detectar cambios de aceleraciones, lo que es crucial para la función de asistencia del dispositivo.

Push button:

Este botón se incorpora para permitir a los usuarios o cuidadores detener alertas una vez que se haya suscitado una.

Alarma sonora buzzer:

Elegido para emitir alertas sonoras en situaciones críticas, garantizando que los cuidadores o familiares sean notificados rápidamente en caso de encontrarse cercas del usuario.

Porta baterías:

Se utiliza para alojar las baterías recargables de manera segura y organizada, facilitando su acceso para el cambio y la carga.

Baterías recargables:

Seleccionadas por su eficiencia energética y capacidad de ser recargadas, asegurando un funcionamiento continuo del dispositivo

Cargador de baterías:

Incluido para facilitar la recarga de las baterías recargables, permitiendo que el dispositivo esté siempre listo para su uso.

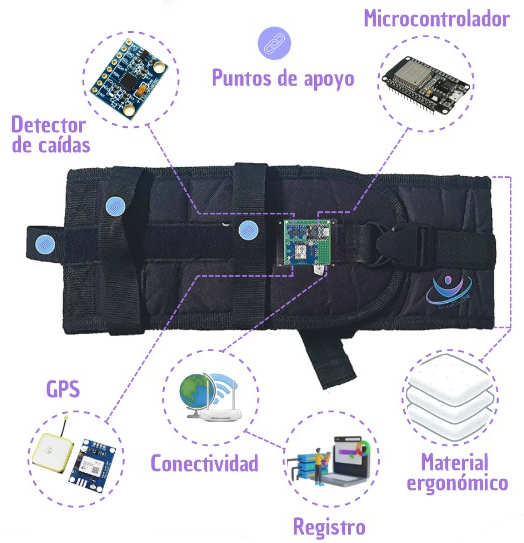
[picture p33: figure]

Diseño físico

El dispositivo está fabricado con tela negra de alta resistencia y relleno acolchonado, garantizando mayor comodidad durante el uso. Se diseñó con un enfoque ergonómico para ajustarse al cuerpo del usuario sin ser restrictivo, manteniendo un aspecto visual atractivo que lo hace adecuado para el uso diario.

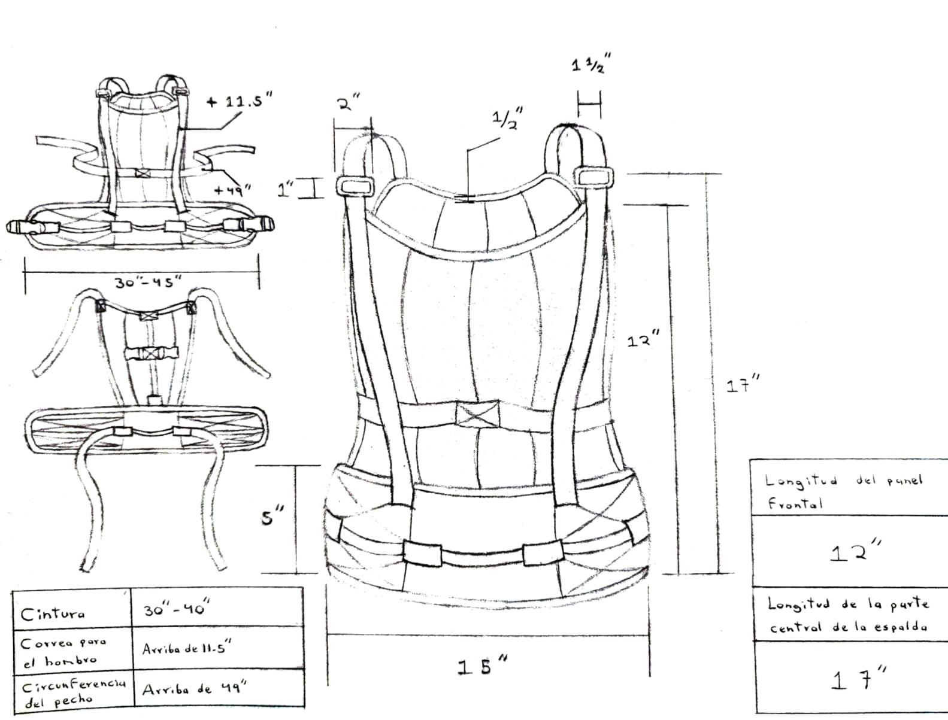
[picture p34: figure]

Los sensores están alojados en una carcasa protectora que a su vez están integrados de manera estratégica en compartimientos diseñados específicamente para no incomodar al usuario. Esta disposición permite una recolección de datos eficiente, garantizando que los sensores funcionen correctamente y no sean un impedimento en la movilidad.

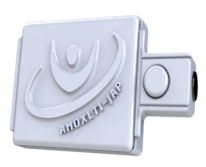
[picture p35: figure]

Los botones están colocados en posiciones accesibles para el usuario y cuidadores, asegurando que sean fáciles de usar en situaciones de emergencia. Se ha considerado el uso de diferentes formas y texturas en los botones para facilitar su identificación táctil, permitiendo una respuesta rápida en momentos críticos.

El buzzer se ubica en un lugar diseñado para ser audible sin ser molesto, permitiendo que las alertas sean percibidas sin causar incomodidad al usuario ni a quienes se encuentren cerca.

Las baterías, el porta-baterías y otros componentes electrónicos están organizados en compartimientos seguros y discretos, protegiéndolos de daños físicos y garantizando que no sean visibles ni interferentes en la estética general del diseño.

El diseño incluye correas ajustables y materiales acolchonados que aseguran la comodidad y seguridad del usuario durante su uso prolongado. Esto se traduce en una experiencia de uso positiva, donde el dispositivo se siente ligero y adaptable a diferentes tipos de cuerpo, fomentando su aceptación por parte de los usuarios.

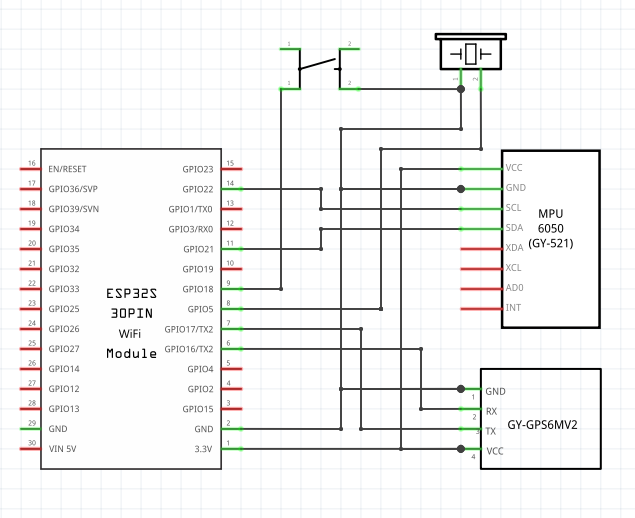
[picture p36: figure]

Desarrollo del prototipo

En esta fase, se integraron todos los componentes en el diseño final del cinturón/chaleco. Se realizaron conexiones precisas entre el microcontrolador ESP32, el geolocalizador GPS Neo-6M y el giroscopio/acelerómetro MPU6050. Para llevar a cabo esta integración, se utilizó una protoboard para facilitar las conexiones iniciales y probar la funcionalidad de cada sensor antes de su ensamblaje definitivo.

Durante el ensamblaje, se realizaron ajustes necesarios para asegurar que todos los sensores funcionaran correctamente dentro del cinturón. Esto incluyó la verificación de las conexiones eléctricas y la programación inicial de la ESP32 para asegurar que pudiera recibir y procesar datos de los sensores sin inconvenientes.

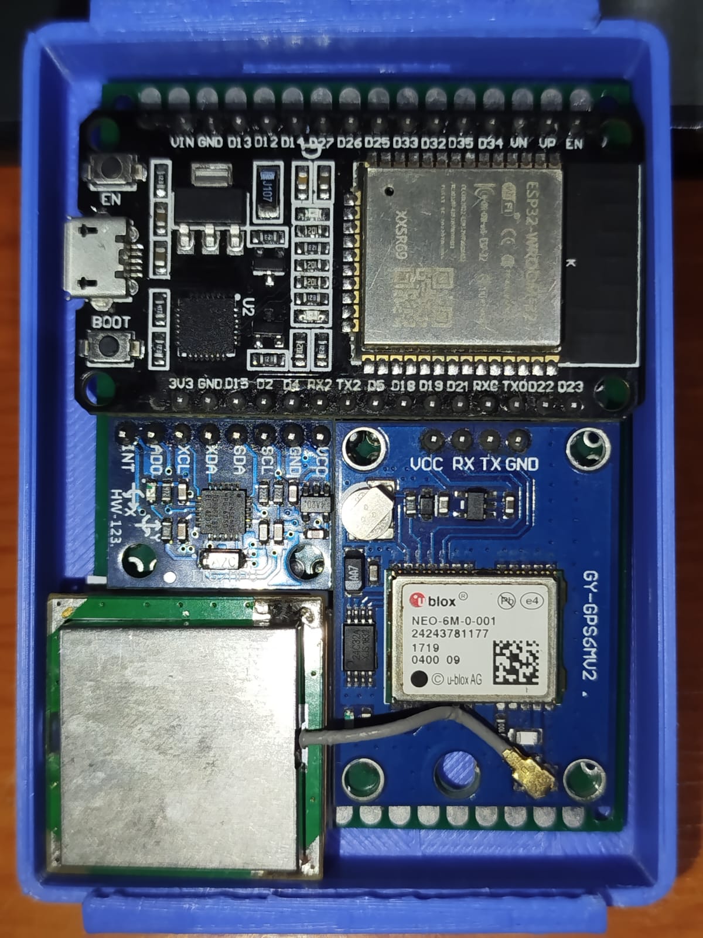
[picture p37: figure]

Se llevaron a cabo pruebas de funcionamiento individuales para cada componente. Por ejemplo, se verificó la precisión del GPS en diferentes entornos y se probó el giroscopio para asegurar que podía detectar correctamente los movimientos y caídas. Cualquier irregularidad se documentó y se ajustó durante la fase de integración.

A lo largo del proceso, se encontraron algunos desafíos, como la necesidad de ajustar las posiciones de los sensores para maximizar su eficacia sin incomodar al usuario. Se solucionaron estos problemas modificando el diseño físico del cinturón y la programación de la ESP32, lo que permitió una mejor comunicación entre los componentes.

Finalmente, después de múltiples iteraciones y pruebas, se logró un prototipo funcional que cumplía con los objetivos establecidos en la fase de planificación. Este prototipo permite a los usuarios disfrutar de un dispositivo médico vestible que no solo proporciona seguridad en situaciones críticas, sino que también es cómodo y fácil de usar.

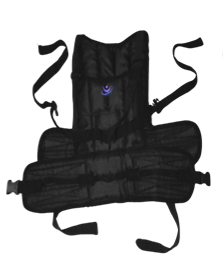
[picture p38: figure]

Pruebas iniciales

Se llevaron a cabo pruebas exhaustivas para verificar el correcto funcionamiento del prototipo. En primer lugar, se simularon caídas utilizando un peso de aproximadamente 5 kg, que representa un usuario mayor de edad. Se dejaron caer el peso desde una altura de 1 metro sobre una superficie suave para evitar daños al dispositivo, mientras se monitoreaba la respuesta del giroscopio.

Durante las pruebas de localización, se utilizó un entorno bajo techo, así como un entorno al aire libre para garantizar que el GPS Neo-6M pudiera recibir una señal clara. Se realizaron varias pruebas de ubicación en diferentes momentos del día, y se registró el tiempo que tardaba el sistema en obtener la ubicación y emitir una alerta, además, también existen pruebas en cuatro ciudades diferentes del norte del país, garantizando que la conectividad del GPS a la base de datos funciona de manera correcta.

Los resultados de las pruebas fueron alentadores; el GPS mostró un rendimiento excelente, logrando una precisión del 100% en la localización y activando las alertas adecuadas en situaciones de emergencia. Sin embargo, el giroscopio presentó algunos problemas, ya que no siempre detectaba las caídas correctamente. En ocasiones, falló en la detección de caídas y, en otras, generó falsos positivos al registrar movimientos que no correspondían a una caída real. Este resultado indicó la necesidad de realizar ajustes en el algoritmo de procesamiento de datos del giroscopio para mejorar su fiabilidad.

Los datos recolectados se almacenaron automáticamente en la base de datos de la plataforma web desarrollada, sin embargo, también se analizaron manualmente, identificando patrones que resaltaban la necesidad de optimizar la calibración del giroscopio y ajustar los parámetros del mismo para mejorar su eficacia. Como resultado, se implementaron ajustes en la programación de la ESP32 para filtrar las lecturas erróneas y mejorar la precisión del sistema.

Finalmente, se planificaron pruebas adicionales en entornos más diversos y bajo diferentes condiciones climáticas para validar la robustez del prototipo y asegurar que funcionara de manera confiable en situaciones del mundo real. Al final, hubo un total de 1156 pruebas del prototipo de manera controlada.

Optimización

Tras las pruebas iniciales, se realizaron varias mejoras en el código del sistema y ajustes en el diseño del cinturón para optimizar el consumo de batería y aumentar la durabilidad del dispositivo. En el código, se implementaron algoritmos de ahorro de energía, que permiten al ESP32 entrar en un modo de bajo consumo cuando no se detectan movimientos. Esto ha resultado en una mejora significativa en la duración de la batería, aumentando el tiempo de uso continuo del dispositivo.

Consumo energético del sensor

Componentes:

ESP32 – 160mA

MPU6050 – 3.9mA

NEO-6M – 45mA

Buzzer Pasivo – 15mA (5%)

Baterías recargables – 2500mAh

Fórmula de consumo de energía:

Duración (h)=(Capacidad Batería (mAh))/(Consumo Componentes (mA))

Consumo total:

160mA+3.9mA+45mA+0.75mA =209.65mA

Duración total:

Duración total = (2500mA)/(209.65mA) =11.924h

Además, se ajustaron algunos compartimientos del cinturón/chaleco para mejorar la accesibilidad y la comodidad. Por ejemplo, se mejoró el acceso al botón de emergencia y al porta-baterías, permitiendo un uso y accesibilidad más fácil y rápida en situaciones críticas. La reubicación del buzzer en la parte superior del dispositivo también ayudó a que el sonido fuera más claro y audible sin resultar molesto.

Como resultado de estas optimizaciones, se notó una mejora en la experiencia general del usuario, con una duración de batería extendida y un acceso más intuitivo a los controles del dispositivo. Se llevaron a cabo pruebas adicionales para validar estas mejoras, confirmando que el prototipo ahora cumplía con los estándares de funcionalidad y comodidad establecidos en la fase de planificación.

Ejecución y construcción

A continuación, se muestra el desarrollo del prototipo desde el 27 de abril de 2022 hasta el 31 de octubre de 2024.

Fecha | Ubicación | Pruebas realizadas
27 de abril de 2022 | Guadalupe Victoria | Ensamblaje del prototipo inicial en protoboard.
28 de abril de 2022 | Guadalupe Victoria | Pruebas iniciales del prototipo en protoboard.
29 de abril de 2022 | Guadalupe Victoria | Creación del prototipo en PCB.
30 de abril – 3 de mayo de 2022 | Guadalupe Victoria | Pruebas en Python con el prototipo en PCB, validación de alertas.
21 de junio – 25 junio de 2022 | Guadalupe Victoria | Pruebas de integración de WhatsApp en el sistema, simulando caídas y monitoreando la funcionalidad del sistema de alertas.
26 de junio de 2022 | Guadalupe Victoria | Mejora del prototipo en PCB para mejorar la detección de caídas.
27 de junio – 13 de julio de 2022 | Guadalupe Victoria | Pruebas de integración de Google Maps, simulando caídas y monitoreando la funcionalidad del sistema de alertas y geolocalización.
25 de julio – 28 de julio de 2022 | Matehuala | Desarrollo de página web y base de datos en Visual Studio y MySQL con HTML, CSS, JAVA SCRIPT y PHP.
29 de julio – 14 de agosto de 2022 | Guadalupe Victoria | Simulaciones de caídas y movimientos bruscos en Visual Studio, WhatsApp y Google Maps, evaluando la precisión del sistema de alertas y geolocalización junto a la página web.
15 de agosto de 2022 | Guadalupe Victoria | Cálculos del consumo energético del dispositivo.
10 de enero – 25 de enero de 2023 | Matehuala | Pruebas con sensores adicionales para evaluar si el sistema responde adecuadamente a diferentes tipos de caídas y movimientos bruscos.
1 de marzo – 15 de marzo de 2023 | Guadalupe Victoria | Evaluación de la durabilidad del prototipo en condiciones simuladas de uso prolongado.
10 de abril – 20 de abril de 2023 | Guadalupe Victoria | Mejoras en la interfaz de usuario para la página web, integrando visualización de alertas en tiempo real y un panel de control.
5 de mayo – 15 de mayo de 2023 | Guadalupe Victoria | Implementación de un formulario de registro para llevar un control de las cuentas o perfiles de los usuarios en la página web.
20 de junio – 30 de junio de 2023 | Matehuala | Pruebas extendidas de geolocalización en diferentes puntos de la ciudad para ver la precisión y fiabilidad del GPS.
15 de julio – 30 de julio de 2023 | Matehuala | Optimización del código para reducir el consumo energético del dispositivo y aumentar la duración de la batería.
1 de agosto – 6 de agosto de 2024 | Durango | Diseño y elaboración del cinturón y chaleco con los aditamentos necesarios para la seguridad y asistencia.
7 de agosto – 12 de agosto de 2024 | Guadalupe Victoria | Implementación del dispositivo electrónico al dispositivo vestible.
13 de agosto – 15 de agosto de 2024 | Guadalupe Victoria | Ajustes finales en la calibración y posicionamiento del sensor.
16 de agosto – 18 de agosto de 2024 | Matehuala | Pruebas simuladas de caídas con el prototipo final en San Luis Potosí.
19 de agosto de 2024 | Durango | Pruebas simuladas de caídas con el prototipo final en Durango.
3 de septiembre – 5 de septiembre de 2024 | Monterrey | Pruebas simuladas de caídas con el prototipo final en Nuevo León.
19 de octubre – 31 de octubre de 2024 | Guadalupe Victoria | Pruebas del último prototipo con mejoras, evaluando la respuesta del sistema con simulaciones manuales de caídas.

Resumen final de pruebas realizadas a lo largo del desarrollo:

- 2022: 220 pruebas
- 2023: 390 pruebas
- 2024: 546 pruebas

Condiciones de prueba del prototipo

Las pruebas del prototipo se llevaron a cabo bajo diferentes condiciones para evaluar su rendimiento y funcionalidad. A continuación, se detallan las cantidades de pruebas realizadas en cada tipo de situación.

Tipos de prueba | Descripción | Cantidad
Pruebas en entornos controlados | Pruebas del prototipo en situaciones controladas para evaluar la detección de caídas. | 600
Pruebas de geolocalización en condiciones variables | Evaluación de la precisión del sistema GPS en diferentes entornos y condiciones climáticas. | 556

Eficiencia en entornos controlados

Se realizaron diversas pruebas en entornos controlados para evaluar el rendimiento del prototipo. Los resultados indican la efectividad de las funcionalidades implementadas y la integración de sensores bajo condiciones específicas.

Persona | Pruebas realizadas | Tasa de verdaderos positivos (%) | Tasa de falsos positivos (%)
1 | 50 | 94 | 6
2 | 50 | 95 | 5
3 | 50 | 96 | 4
4 | 50 | 93 | 7
5 | 50 | 95 | 5
6 | 50 | 97 | 3
7 | 50 | 95 | 5
8 | 50 | 92 | 8
9 | 50 | 98 | 2
10 | 50 | 94 | 6
11 | 50 | 95 | 5
12 | 50 | 96 | 4
Total | 600 | 95% | 5%

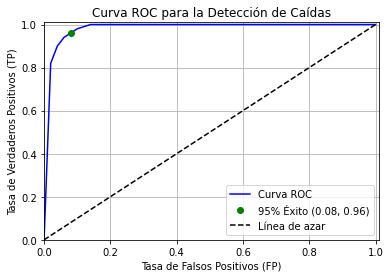
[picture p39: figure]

Eficiencia de geolocalización

Se llevaron a cabo pruebas para evaluar la precisión del sistema de geolocalización en diferentes condiciones climáticas. Esta tabla muestra la efectividad del GPS en entornos variados.

Condición climática | Pruebas realizadas | Tasa de localización precisa (%)
Soleado | 140 | 100
Nublado | 130 | 98
Lluvia ligera | 100 | 97
Lluvia intensa | 90 | 96
Ventoso | 96 | 95
Total | 556 | 98.5%

Eficiencia General =(Eficiencia de detección de caídas+Eficiencia de geolocalización)/2

Eficiencia General =(95+98.5)/2≈96.75%

La eficiencia del dispositivo es de aproximadamente un 96.75%.

Habilidades de ingeniería adquiridas

Diseño y Prototipado

Se desarrolló la capacidad para conceptualizar y crear prototipos funcionales de dispositivos y sistemas electrónicos. Se aprendió a utilizar herramientas de diseño para esbozar ideas y traducirlas en modelos físicos. Esto incluyó la elaboración de prototipos iniciales en protoboard y su posterior transición a PCB, asegurando que el diseño cumpliera con los requisitos funcionales y estéticos.

Integración de Sistemas Electrónicos

Se combinaron diferentes componentes electrónicos, como sensores, microcontroladores y módulos de comunicación, para crear un sistema cohesivo. Se aprendió a gestionar la interconexión de hardware y software, asegurando que cada parte del sistema funcionara en armonía. Esto implicó la implementación de protocolos de comunicación y la configuración de dispositivos para el intercambio de datos en tiempo real.

Resolución de Problemas

Se desarrollaron habilidades críticas para identificar, analizar y resolver problemas complejos que surgieron durante el desarrollo del proyecto. Se aprendió a aplicar un enfoque sistemático para descomponer problemas en partes más manejables, realizar diagnósticos y ejecutar soluciones efectivas. Esta habilidad fue fundamental para mejorar la fiabilidad y el rendimiento del dispositivo.

Trabajo en Equipo y Comunicación

Se fomentó la colaboración y la comunicación efectiva dentro de un equipo multidisciplinario. Se aprendió a compartir ideas, discutir problemas y coordinar tareas con compañeros, así como a presentar resultados y avances de manera clara y concisa. Esta experiencia permitió entender la importancia de la sinergia en el desarrollo de proyectos complejos.

Programación

Se adquirieron habilidades en múltiples lenguajes de programación, incluyendo Python, C++ y PHP. Se aprendió a desarrollar software para controlar hardware, procesar datos y crear interfaces de usuario. Esta experiencia incluyó la programación de algoritmos para la detección de caídas y la gestión de alertas, así como la integración con APIs externas, como WhatsApp y Google Maps.

Soldadura y Diseño de Circuitos Eléctricos Manuales

Se mejoraron las habilidades prácticas en soldadura, lo que permitió ensamblar componentes electrónicos en PCBs de manera eficiente. Se aprendieron técnicas de soldadura con estaño y el uso de herramientas adecuadas, lo que resultó en conexiones eléctricas fiables y duraderas. También se adquirieron conocimientos sobre el diseño de circuitos eléctricos, lo que permitió crear esquemas funcionales y realizar ajustes necesarios en el diseño.

Organización de Espacios

Se desarrollaron habilidades de organización y gestión del espacio de trabajo, creando un entorno óptimo para la experimentación y el desarrollo. Se aprendió a clasificar herramientas, componentes y documentos de manera eficiente, facilitando un flujo de trabajo más productivo y minimizando el desorden.

Selección de Componentes Viables

Se aprendió a evaluar y seleccionar componentes electrónicos adecuados para el proyecto, considerando factores como coste, disponibilidad, compatibilidad y rendimiento. Esta habilidad es fundamental para garantizar que el diseño sea económicamente viable y funcional.

HTML, CSS, JavaScript, PHP

Se adquirieron competencias en el desarrollo web, aprendiendo a crear y gestionar sitios web utilizando HTML para la estructura, CSS para el diseño visual y JavaScript para la interactividad. También se implementaron funcionalidades del lado del servidor con PHP, lo que permitió gestionar bases de datos y formularios de usuario.

C++, MySQL, XAMPP, Visual Studio

Mejoraron las habilidades en programación con C++ y en el manejo de bases de datos utilizando MySQL. Se aprendió a utilizar XAMPP como entorno de desarrollo para crear aplicaciones web locales y Visual Studio como IDE para proyectos de software, optimizando el flujo de trabajo.

Conexión entre Software y Hardware

Se aprendió a establecer conexiones efectivas entre el software y el hardware, desarrollando aplicaciones que interactúan directamente con dispositivos electrónicos. Esto incluyó el uso de protocolos de comunicación como I2C y UART, así como el desarrollo de controladores e interfaces de usuario para el manejo de dispositivos.

Hostinger e Interconectividad entre Plataformas

Se experimentó con el alojamiento web a través de Hostinger, lo que permitió gestionar aplicaciones en línea. Se aprendió sobre la interconectividad entre diferentes plataformas, como WhatsApp, Google Maps y redes sociales, integrando funcionalidades que permiten la comunicación y el intercambio de información entre aplicaciones.

Diseño Textil y Diseño 3D

Se desarrollaron habilidades en el diseño textil, aprendiendo a crear patrones y prototipos de vestimentas funcionales que integran tecnología. Además, se adquirieron competencias en diseño 3D utilizando software especializado, lo que permitió modelar y visualizar ideas antes de su fabricación.

Impresión 3D

Se aprendió a utilizar impresoras 3D para fabricar prototipos y piezas personalizadas, lo que mejoró significativamente la capacidad de creación de modelos físicos. Se realizaron investigaciones para entender mejor las propiedades de los materiales y las técnicas de impresión, optimizando el proceso de producción.

Resultados

El desarrollo del proyecto ha resultado en una solución innovadora y viable para el monitoreo y alerta de caídas en adultos mayores, destacándose por su enfoque en accesibilidad, tecnología avanzada y bajo costo. A través de la integración de sensores de alta precisión, tecnología IoT, y conectividad con plataformas como WhatsApp, Google Maps y la página oficial del proyecto, el prototipo proporciona una respuesta rápida y eficiente ante incidentes críticos como caídas, mejorando significativamente la calidad de vida y seguridad de los usuarios.

Innovación y Comparación con Competencias

Comparado con las soluciones existentes en el mercado, tales como el sistema SkyAngel 4G y otras alternativas que usan tecnologías como Kinect 2.0 y redes neuronales LSTM, el presente prototipo ofrece ventajas clave:

1. Costo reducido: Mientras que dispositivos similares como el SkyAngel 4G cuestan alrededor de $179.79 USD, el cinturón auxiliar tiene un costo de fabricación previsto significativamente menor, lo que lo hace más accesible para una mayor parte de la población.

2. Integración de comunicación en tiempo real: A diferencia de sistemas que solo envían alertas por correo o plataformas limitadas, la integración con WhatsApp permite notificaciones inmediatas y fáciles de configurar para familiares y cuidadores en cualquier ubicación.

3. Personalización y confort: El dispositivo ha sido diseñado pensando en la comodidad del usuario, con sujetadores personalizados que facilitan el uso diario sin incomodidad.

Impacto en Costos y Procesos

El proyecto también tiene un impacto directo en la reducción de costos y la eficiencia en la atención médica. Al proporcionar alertas tempranas y monitoreo continuo, el dispositivo ayuda a prevenir hospitalizaciones prolongadas y reduce los costos asociados con las complicaciones derivadas de caídas. Esta innovación es particularmente relevante para el sistema de salud, donde las caídas en adultos mayores representan una carga significativa.

Nuevas Alternativas y Posibilidades

A nivel tecnológico, el cinturón auxiliar es una propuesta alineada con las megatendencias globales de envejecimiento poblacional y atención médica personalizada. Además, el uso de tecnologías disruptivas como IoT, análisis de datos y conectividad inalámbrica representa un avance significativo en la gestión de la salud en el hogar. Esto abre nuevas posibilidades para escalar la solución a nivel local, regional e incluso global, adaptándose a diversos entornos y necesidades de los usuarios.

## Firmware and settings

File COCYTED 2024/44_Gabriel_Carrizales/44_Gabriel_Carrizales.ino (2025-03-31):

#include <Wire.h>
#include <WiFi.h>
#include <MPU6050.h>
#include <HTTPClient.h>
#include <TinyGPS++.h>

MPU6050 mpu;

const char *ssid = "Redmi Note 13"; //                                   "INFINITUM86C2";          "Redmi Note 13";         "Galaxy S20";
const char *password = "22072207"; //                                   "ELd4TfVbHW";             "22072207";          "123456789";
const char *host = "192.168.1.71"; // IP local de tu computadora
const int buzzerPin = 5;
const int buttonPin = 18;

WiFiClient client;

String token = "Bearer EAAQ8j5c9GKUBOy43CLu6XuIIJ4xFZB56gclkmwGj7Nc7lw4Wh3NY9mf3gTYrQboTwymBh1i8MVvQ7jEEJrakcUqq5Lf8B4QZAOsdLzZCs5ckZAjU1elzN23ZCxTao4zRaP3TxAU7QxWBMuQ6KRrOa9gZAltv7ZBgHVuwz7is2FdEXFBUwc7FyyAeDKWaTzEWPqh";
String servidor = "https://graph.facebook.com/v19.0/345081398691756/messages";

// Configuración del id del dispositivo
String idDispositivo = "44"; // Gabriel_Carrizales

enum class Posicion { Normal, BocaArriba, BocaAbajo, LadoIzquierdo, LadoDerecho };
Posicion posicionActual = Posicion::Normal;
Posicion ultimaPosicionValida = Posicion::Normal; // Almacena la última posición válida detectada
Posicion posicionCaidaEsperada = Posicion::Normal; // Almacena la posición esperada para la caída
unsigned long ultimoCambioPosicion = 0;
const unsigned long tiempoMinimoCambioPosicion = 5000;
bool alarmaActivada = false;
bool estadoFuerte = true;
bool caidaDetectada = false; // Indica si se detectó una caída en una posición inválida
bool datosEnviados = false; // Indica si los datos de la caída han sido enviados
bool caidaInformada = false; // Variable de estado para controlar si ya se ha enviado la informacion de la caida
bool alertaEnviada = false; // Para asegurar que la alerta solo se envie una vez por caida
bool caidaConfirmada = false; // Nueva bandera para confirmar la caída

TinyGPSPlus gps;
#define RXD2 16
#define TXD2 17
HardwareSerial neogps(1);

bool deteccion_de_caida();
void actualizarPosicion();
bool enviarDatos(String posicionCaida);
String obtenerDatosGPS();
String obtenerFechaHora();
void alternarBuzzer();
void detenerBuzzer();
String obtenerNombrePosicion(Posicion posicion);

void setup() {
  Serial.begin(115200);
  Wire.begin();
  mpu.initialize();

  Serial.println("Conectando a la red WiFi...");
  WiFi.begin(ssid, password);
  while (WiFi.status() != WL_CONNECTED) {
    delay(500);
    Serial.print(".");
  }
  Serial.println("\nWiFi conectado.");

  pinMode(buzzerPin, OUTPUT);
  pinMode(buttonPin, INPUT_PULLUP);

  neogps.begin(9600, SERIAL_8N1, RXD2, TXD2);
}

void loop() {
  static unsigned long lastInternetCheckTime = 0;
  if (millis() - lastInternetCheckTime >= 10000) {
    lastInternetCheckTime = millis();
    if (WiFi.status() == WL_CONNECTED) {
      Serial.println("Conectado a Internet.");
    } else {
      Serial.println("Error: No se pudo conectar a Internet.");
    }
  }

  if (deteccion_de_caida()) {
    Serial.println("CAÍDA DETECTADA");

    // Esperar 5 segundos para obtener la nueva posición
    delay(5000);
    actualizarPosicion();
    String posicionCaida = obtenerNombrePosicion(posicionActual);
    Serial.println("Posición después de la caída: " + posicionCaida);

    if (posicionActual != Posicion::Normal) {
      caidaDetectada = true;

      // Solo proceder si no se ha enviado una alerta aún
      if (!alertaEnviada) {
        posicionCaidaEsperada = posicionActual; // Guarda la posición esperada para la caída
        ultimaPosicionValida = posicionActual; // Actualiza la última posición válida
        if (enviarDatos(posicionCaida)) {
          Serial.println("Datos enviados al servidor.");
          alertaEnviada = true; // Marcar alerta como enviada
          caidaConfirmada = true; // Confirmar que la caída ha sido gestionada
          datosEnviados = true; // Marcar datos como enviados
        } else {
          Serial.println("Error al conectar con el servidor.");
        }
        alarmaActivada = true; // Solo activar la alarma si se envían los datos correctamente
      }
    } else {
      caidaDetectada = true; // Marcar caída detectada para esperar la posición válida
    }
    delay(1000);
  } else {
    // Si no se detecta una caída, reiniciar el control de alerta si se ha gestionado una caída
    if (caidaDetectada && alertaEnviada) {
      caidaDetectada = false;
      caidaInformada = false;
      alertaEnviada = false;
      caidaConfirmada = false;
      datosEnviados = false; // Reiniciar datos enviados
    }
  }

  actualizarPosicion();

  // Enviar datos si se detecta una posición válida después de una caída
  if (caidaDetectada && posicionActual != Posicion::Normal && posicionActual != ultimaPosicionValida && posicionActual != posicionCaidaEsperada) {
    if (!caidaInformada && caidaConfirmada && datosEnviados) {
      // Código para enviar datos y activar alarma
      if (enviarDatos(obtenerNombrePosicion(posicionActual))) {
        Serial.println("Datos enviados al servidor.");
        caidaInformada = true; // Marca que la caída ha sido informada
      }
    }
  }

  // Manejo de la alarma
  if (alarmaActivada) {
    alternarBuzzer();
    if (digitalRead(buttonPin) == LOW) {
      detenerBuzzer();
      alarmaActivada = false; // Restablecer alarmaActivada a false
      caidaInformada = false; // Restablecer caidaInformada a false
      alertaEnviada = false; // Restablecer alertaEnviada a false para nuevas caídas
      caidaConfirmada = false; // Restablecer caidaConfirmada a false para nuevas caídas
      datosEnviados = false; // Restablecer datosEnviados a false
      Serial.println("Alarma detenida por el botón.");
    }
  }

  if (digitalRead(buttonPin) == LOW) {
    detenerBuzzer();
    alarmaActivada = false;
    caidaInformada = false; // Restablecer la variable de estado en false
    alertaEnviada = false; // Restablecer alertaEnviada a false para nuevas caídas
    caidaConfirmada = false; // Restablecer caidaConfirmada a false para nuevas caídas
    datosEnviados = false; // Restablecer datosEnviados a false
    Serial.println("Alarma detenida por el botón.");
  }

  delay(100);

  while (neogps.available() > 0) {
    gps.encode(neogps.read());
  }
}

bool deteccion_de_caida() {
  int16_t ax, ay, az;
  mpu.getAcceleration(&ax, &ay, &az);

  float acceleration = sqrt(ax * ax + ay * ay + az * az);
  float threshold = 20000.0;

  if (posicionActual != Posicion::Normal && acceleration > threshold) {
    return true;
  } else {
    return false;
  }
}

bool enviarDatos(String posicionCaida) {
  bool success = false;

  if (WiFi.status() == WL_CONNECTED) {
    // Obtener datos GPS
    String gpsData = obtenerDatosGPS();
    String latitud = gpsData.substring(0, gpsData.indexOf(','));
    String longitud = gpsData.substring(gpsData.indexOf(',') + 1);

    // Enviar datos a la página web
    HTTPClient http;
    http.begin("https://home.amoxtli-jap.com/php/recibir_datos.php"); // URL local del archivo PHP
    http.addHeader("Content-Type", "application/x-www-form-urlencoded");

    // Solo enviar datos si la posición no es "Normal"
    if (posicionCaida != "Normal") {
      String payload = "id_dispositivo=" + idDispositivo + "&latitud=" + latitud + "&longitud=" + longitud + "&fecha_hora=" + obtenerFechaHora() + "&posicion_caida=" + posicionCaida;
      Serial.println("Enviando datos con payload: " + payload);

      int httpResponseCode = http.POST(payload);
      if (httpResponseCode > 0) {
        String response = http.getString();
        Serial.println(response);
        success = true;
      } else {
        Serial.print("Error code: ");
        Serial.println(httpResponseCode);
      }
      http.end();
    }

    // Enviar alerta a WhatsApp
    HTTPClient httpWhatsApp;
    httpWhatsApp.begin(servidor);
    httpWhatsApp.addHeader("Content-Type", "application/json");
    httpWhatsApp.addHeader("Authorization", token);

    String payloadWhatsApp = "{\"messaging_product\":\"whatsapp\",\"to\":\"526761055560\",\"type\":\"text\",\"text\":{\"body\":\"¡Alerta de caída! Hemos detectado que Gabriel ha sufrido una caída. Ingresa a este enlace inmediatamente para obtener información y auxiliar a tu familiar: https://home.amoxtli-jap.com/SignIn_SignUp/SignIn.php\"}}";
    Serial.println("Enviando mensaje de WhatsApp con payload: " + payloadWhatsApp);

    int httpPostCode = httpWhatsApp.POST(payloadWhatsApp);
    if (httpPostCode > 0) {
      int httpResponseCode = httpWhatsApp.GET();
      if (httpResponseCode > 0) {
        Serial.print("Código de respuesta: ");
        Serial.println(httpResponseCode);
        String response = httpWhatsApp.getString();
        Serial.println(response);
        success = true;
      } else {
        Serial.print("Error code: ");
        Serial.println(httpResponseCode);
      }
    } else {
      Serial.print("Error code: ");
      Serial.println(httpPostCode);
    }
    httpWhatsApp.end();
  } else {
    Serial.println("No hay conexión WiFi.");
  }

  return success;
}

String obtenerDatosGPS() {
  if (gps.location.isValid()) {
    return String(gps.location.lat(), 6) + "," + String(gps.location.lng(), 6);
  } else {
    return "0.0,0.0";
  }
}

String obtenerFechaHora() {
  // Obtener la hora UTC del GPS
  int year = gps.date.year();
  int month = gps.date.month();
  int day = gps.date.day();
  int hour = gps.time.hour();
  int minute = gps.time.minute();
  int second = gps.time.second();
  
  // Ajustar a la zona horaria local (ejemplo: UTC-6)
  int timezoneOffset = -6; // Cambia esto según tu zona horaria
  hour += timezoneOffset;

  // Manejar el cambio de día y fecha si es necesario
  if (hour < 0) {
    hour += 24;
    day -= 1;
    // Ajustar el mes y año si es necesario
    if (day < 1) {
      month -= 1;
      if (month < 1) {
        month = 12;
        year -= 1;
      }
      // Ajustar el día del mes según el nuevo mes y año
      day = getDaysInMonth(month, year);
    }
  } else if (hour >= 24) {
    hour -= 24;
    day += 1;
    // Ajustar el mes y año si es necesario
    if (day > getDaysInMonth(month, year)) {
      day = 1;
      month += 1;
      if (month > 12) {
        month = 1;
        year += 1;
      }
    }
  }

  // Formatear la fecha y hora en formato de 24 horas
  char fechaHora[20];
  sprintf(fechaHora, "%04d-%02d-%02d %02d:%02d:%02d", year, month, day, hour, minute, second);
  
  return String(fechaHora);
}

int getDaysInMonth(int month, int year) {
  switch (month) {
    case 4: case 6: case 9: case 11: return 30;
    case 2: return (year % 4 == 0 && year % 100 != 0) || (year % 400 == 0) ? 29 : 28;
    default: return 31;
  }
}

void alternarBuzzer() {
  if (estadoFuerte) {
    tone(buzzerPin, 900);
    delay(500);
  } else {
    tone(buzzerPin, 500);
    delay(500);
  }
  noTone(buzzerPin);
  estadoFuerte = !estadoFuerte;
}

void detenerBuzzer() {
  noTone(buzzerPin);
}

void actualizarPosicion() {
  int16_t ax, ay, az;
  mpu.getAcceleration(&ax, &ay, &az);

  float pitch = atan2(-ax, sqrt(ay * ay + az * az)) * RAD_TO_DEG;
  float roll = atan2(ay, az) * RAD_TO_DEG;

  Posicion nuevaPosicion = Posicion::Normal;

  // Ajustar umbrales y tolerancias
  float umbralLado = 16000.0;
  float umbralCuerpo = 14000.0;

  if (pitch > 45.0 && pitch < 135.0 && roll > -45.0 && roll < 45.0) {
    nuevaPosicion = Posicion::Normal;  // De pie o sentado
  } else if (az > umbralCuerpo) {
    nuevaPosicion = Posicion::BocaArriba;  // Boca arriba
  } else if (az < -umbralCuerpo) {
    nuevaPosicion = Posicion::BocaAbajo;  // Boca abajo
  } else if (ay < -umbralLado) {
    nuevaPosicion = Posicion::LadoIzquierdo;  // Lado izquierdo
  } else if (ay > umbralLado) {
    nuevaPosicion = Posicion::LadoDerecho;  // Lado derecho
  }
    // Verificar si ha pasado suficiente tiempo desde el último cambio
    if (nuevaPosicion != posicionActual && millis() - ultimoCambioPosicion > tiempoMinimoCambioPosicion) {
        posicionActual = nuevaPosicion;
        ultimoCambioPosicion = millis();
        Serial.print("Nueva posición detectada: ");
        Serial.println(obtenerNombrePosicion(posicionActual));
        if (caidaDetectada && posicionActual != Posicion::Normal) {
            // Enviar datos correspondientes a la caída
            posicionCaidaEsperada = posicionActual; // Actualizar posicionCaidaEsperada
            String posicionCaida = obtenerNombrePosicion(posicionCaidaEsperada);
            if (enviarDatos(posicionCaida)) {
                Serial.println("Datos enviados al servidor.");
                caidaDetectada = false;
                caidaInformada = false;
            } else {
                Serial.println("Error al conectar con el servidor.");
            }
            alarmaActivada = true; // Activar la alarma
            if (caidaDetectada && posicionActual == posicionCaidaEsperada) {
                caidaDetectada = false;
                caidaInformada = false;
            }
        }
    }
}

String obtenerNombrePosicion(Posicion posicion) {
  switch (posicion) {
    case Posicion::Normal:
      return "Normal";
    case Posicion::BocaArriba:
      return "Posicionado Boca Arriba";
    case Posicion::BocaAbajo:
      return "Posicionado Boca Abajo";
    case Posicion::LadoIzquierdo:
      return "Posicionado sobre su Lado Izquierdo";
    case Posicion::LadoDerecho:
      return "Posicionado sobre su Lado Derecho";
    default:
      return "Desconocida";
  }
}

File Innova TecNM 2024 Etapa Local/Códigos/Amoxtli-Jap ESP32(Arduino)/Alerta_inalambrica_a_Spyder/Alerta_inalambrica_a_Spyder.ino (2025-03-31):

#include <Wire.h>
#include <WiFi.h>
#include <MPU6050.h>

MPU6050 mpu;

const char *ssid = "INFINITUM86C2 xd";
const char *password = "ELd4TfVbHW";
const char *host = "192.168.1.70";

WiFiClient client;

void setup() {
  Serial.begin(115200);
  Wire.begin();
  mpu.initialize();
  Serial.println("Conectando a la red WiFi...");
  WiFi.begin(ssid, password);
  while (WiFi.status() != WL_CONNECTED) {
    delay(500);
    Serial.print(".");
  }
  Serial.println("\nWiFi conectado.");
}

void loop() {
  // Verificar la conexión a Internet cada 10 segundos
  static unsigned long lastInternetCheckTime = 0;
  if (millis() - lastInternetCheckTime >= 10000) {
    lastInternetCheckTime = millis();
    if (WiFi.status() == WL_CONNECTED) {
      Serial.println("Conectado a Internet.");
    } else {
      Serial.println("Error: No se pudo conectar a Internet.");
    }
  }
  
  // Lógica para detectar caídas
  if (deteccion_de_caida()) {
    Serial.println("CAÍDA DETECTADA");
    if (!enviar_alerta()) {
      Serial.println("Error al conectar con el servidor.");
    }
    delay(5000); // Evita enviar múltiples alertas por una misma caída
  }
  
  delay(100);
}

bool deteccion_de_caida() {
  // Variables para almacenar los valores del acelerómetro
  int16_t ax, ay, az;
  
  // Leer los valores del acelerómetro
  mpu.getAcceleration(&ax, &ay, &az);
  
  // Calcular la magnitud del vector de aceleración
  float acceleration = sqrt(ax*ax + ay*ay + az*az);
  
  // Ajustar el umbral para detectar caídas
  float threshold = 27000.0; // Este valor puede requerir ajuste
  
  // Si la aceleración supera el umbral, se considera una caída
  if (acceleration > threshold) {
    return true;
  } else {
    return false;
  }
}

bool enviar_alerta() {
  if (!client.connect(host, 80)) {
    return false;
  }
  client.print("GET /alert HTTP/1.1\r\n");
  client.print("Host: ");
  client.print(host);
  client.print("\r\n\r\n");
  delay(10);
  client.stop();
  return true;
}
